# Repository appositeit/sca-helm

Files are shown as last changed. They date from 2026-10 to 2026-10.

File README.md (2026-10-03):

# sca-helm: standardised pressed SCA helms

This is a research and optimisation toolchain for a small family of pressed-steel helms for SCA armoured combat, initially targeting Lochac. It implements work steps 1–5 of [`docs/design_spec_v0.1.md`](docs/design_spec_v0.1.md).

> **Status: exploratory.** Every result is *geometric feasibility* on a surrogate population under labelled assumptions. Nothing here is a validated design or a claim about protection. The protective-stack, stability, retention and motion-range criteria are reported as **unevaluated** until physical tests exist ([`docs/validation_plan.md`](docs/validation_plan.md)).

## What is here

| Deliverable (spec §11) | Where |
| --- | --- |
| Rules register and current rules matrix | [`config/rules_register.yaml`](config/rules_register.yaml), [`docs/rules_matrix.md`](docs/rules_matrix.md) |
| Source, access and licensing register | [`config/data_sources.yaml`](config/data_sources.yaml), [`docs/data_sources.md`](docs/data_sources.md) |
| Population definition and data-quality report | [`docs/population.md`](docs/population.md), `outputs/*/data_quality.csv` |
| Foam test protocol, property schema, import path | [`docs/foam_test_protocol.md`](docs/foam_test_protocol.md) |
| Fit evaluator and coverage optimiser | `src/scahelm/fit.py`, `src/scahelm/optimise.py` |
| Coverage-vs-tooling plots; per-head assignment and exclusion CSVs | `outputs/<run>/` |
| Candidate dimensions, pad recipes, CAD (STEP/STL/DXF), all labelled EXPLORATORY | `outputs/<run>/candidate_*.csv`, `assignments.csv`, `cad/` |
| Manufacturing comparison, lower compatibility matrix, cost assumptions | [`docs/manufacturing.md`](docs/manufacturing.md), `outputs/<run>/lower_compatibility.csv` |
| Recommendation | [`docs/findings.md`](docs/findings.md) |

## Quick start

```bash
pip install -e .[test,step]          # step = OpenCASCADE bindings for STEP export (optional)
python -m pytest                     # numerical and geometric checks (~5 min)

python -m scahelm run --source synthetic --n 400            # SYNTHETIC fixture, no data needed
python -m scahelm ingest                                     # verify ANSUR II checksums, canonicalise
python -m scahelm run --source ansur2 --n 2000               # surrogate population run
python -m scahelm sweep --source ansur2 --n 900              # sensitivity scenarios (config/scenarios.yaml)
```

Each run writes `outputs/<source>_<scenario>/` containing:

- `SUMMARY.md`
- `manifest.json`: config hash, seed, dataset checksums, package versions, solver
- `config_used.yaml`
- coverage and min-cost tables
- bootstrap intervals
- `assignments.csv`: per head, the assembly, pose and pad recipe, or the exclusion reasons
- plots
- CAD files

## How it works (one paragraph per stage)

1. **Heads** (`heads.py`). Each participant is modelled as a smooth piecewise superquadric. It is built from measured head length, breadth, tragion-to-top height and circumference (which sets the squareness), plus face landmarks. Shape parameters that the scalar tables lack are drawn from *labelled* priors; see `docs/population.md`. Units are mm. Axes: x lateral, y anterior, z superior, with the origin at mid-tragion.
2. **Candidate crowns** (`shells.py`). There are two families:
   - a scaled single-shape *size-only* family;
   - a *shape-variable* grid over inner length, breadth and height.

   Both are smooth convex surfaces, so they have no undercuts. The minimum radius of curvature is enforced. The head-to-shell offset is calibrated so a typical head's pad gaps sit mid-window. *Lower components* (eye line, face-plate depth, chin drop) are offsets from each crown's interface, so every lower can actually be built on its crown.
3. **Liner** (`liner.py`). Discrete pad stacks come from a purchasable catalogue: a protective soft base plus firm or soft fitting layers. A linear series-spring screening model checks installed strain, contact pressure, the 12.7 mm minimum padding, maximum depth and compression reserve. **All foam properties are placeholders**, so stability stays unevaluated.
4. **Fit predicate** (`fit.py`, spec §7). Each criterion returns pass, fail or unevaluated. The geometric checks are:
   - hard contact (intrusion);
   - pad fill in five support zones;
   - unpadded clearance;
   - ear clearance;
   - seam bead;
   - eye line and vertical field of view;
   - nose and chin clearance;
   - the rules-derived 25.4 mm coverage below the chin.

   Head pose is searched over a bounded translation grid. Clearances are true surface distances (minimum over tangent planes for the convex shell), not radial differences. Discretisation bounds are added to the allowances. The fast path (a distance field) re-checks every near-threshold case exactly, and the tests confirm it reproduces the exhaustive evaluation.
5. **Selection** (`optimise.py`). Greedy set cover is the baseline, with an exact MILP (HiGHS via `scipy.optimize.milp`) over the finite catalogue. Dies are counted per architecture:
   - modular: one crown die set per family, with laser-cut lower variants at their own design cost;
   - integrated: each assembly is its own pressing;
   - left and right halves are distinct dies unless configured otherwise.

   The MILP is checked against exhaustive enumeration in the tests. Validation is held out by participant. The bootstrap re-runs the selection, so intervals include selection variability. Results are optimal **over the catalogue only**.

## Labelling conventions

Reports separate **retrieved facts** (rules, dataset properties), **design decisions**, **provisional scenarios** (`config/scenarios.yaml`) and **experimental results**. There are no experimental results yet. Config values carry `[RULE]`, `[DATA]`, `[ASSUMPTION]` or `[DECISION]` tags.

## Data

ANSUR II public files are stored unmodified in `data/raw/ansur2/` (US Army, cleared for unlimited public release), and their sha256 is checked on load. Restricted datasets must never be committed; `data/raw/restricted/` is git-ignored.

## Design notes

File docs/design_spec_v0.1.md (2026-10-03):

# Standardised pressed SCA helms: design and research specification

Version: 0.1 — 4 October 2026  
Status: engineering investigation and local-agent implementation brief; not a validated production design.

## 1. Objective

Design a manufacturable family of steel helms for adult SCA armoured combat, initially targeting Lochac. Minimise the number of expensive press forms while achieving acceptable fit for at least 90% of a defined target population. Fit must include liner stability, protective clearance, retention, vision and lower-head coverage, rather than merely containing the head.

The intended manufacturing approach is two pressed shell halves welded together, with a laser-cut grille and adaptable lower components. Investigate left/right halves joined along a sagittal seam as the working interpretation. Keep the split plane configurable: the original proposal did not establish it definitively. Compare this with a pressed crown plus fabricated lower assembly; do not silently substitute the latter architecture.

The initial deliverable is a reproducible research and optimisation toolchain, candidate dimensions and CAD geometry, and a physical validation plan. Do not assume that three or four forms will achieve 90% coverage; calculate it.

## 2. Design principles and scope

- Use adult external head geometry, including soft tissue, not bare bony skull geometry.
- Model size and shape jointly: length, breadth, height, occipital contour and forehead shape matter. Circumference and cephalic index are descriptive measurements, not sufficient fit criteria.
- Permit a small catalogue of foam materials and interchangeable pad thicknesses. Determine allowable shell oversize from measured displacement and liner behaviour.
- Separate crown geometry from lower face, jaw, eye-line and neck geometry where the manufacturing interface permits it.
- Optimise die cost, liner complexity and production effort together. Laser-cut variants still have assembly, stock and validation costs.
- Keep geometric fit, stability, impact performance and rules compliance as separate reported results.
- Preserve historically plausible appearance, with an open grille and good ventilation as initial preferences. Do not require one crown to support every historical helm type.

Out of scope for the first implementation: certifying protective performance, final press tooling manufacture, and claims about concussion prevention.

## 3. Evidence and rules register

Before fixing design limits, identify the current authoritative Lochac and Society requirements and record version, effective date, URL and relevant sections. Resolve superseded or conflicting documents. Maintain a machine-readable register linking each requirement to its source and verification method.

The official Lochac armour-requirements page retrieved for this brief states minimum completed steel thickness of 1.6 mm, resilient padding of at least 12.7 mm where the helm can contact the head unless an adequate suspension prevents injurious contact, and a separate retention requirement. These are research starting points pending verification against the applicable current handbook. Do not turn a padding-thickness rule directly into a geometric clearance rule without accounting for liner installation and compression.

Extract all applicable seam, face protection, opening, retention, screening, coverage and interior-projection rules. In particular, a laser-cut plate grille must be assessed as its actual geometry and material: a narrow rectangular ligament is not automatically equivalent to a permitted round bar. Distinguish ordinary armoured combat from missile-combat screening requirements.

The earlier discussion's 12.7–25 mm liner envelope, 5/10/15 mm fitting pads and estimated shell counts are hypotheses, not validated requirements. The suggestion that soft foam should be the impact layer and firm foam merely a fitting layer is also unproven: evaluate the whole stack.

## 4. Population and data acquisition

Define the denominator explicitly: ideally adults likely to participate in Lochac armoured combat. Public occupational or military samples are proxies. Report their limitations rather than claiming Australian population coverage from them.

Investigate these sources in order:

1. NIOSH anthropometric measurements and ISO digital headforms: establish exactly which individual records, cranial surfaces, weights and licences are downloadable.
2. Accessible military/civilian 3-D anthropometric collections, such as CAESAR or ANSUR-related resources: distinguish measurement tables from scans and check access/licensing.
3. EN 960 helmet-testing headforms as reproducible geometric references, subject to lawful access to the standard or licensed CAD. Standard headforms are test geometries, not a representative population sample.
4. A supplementary consenting local participant sample for checking population transfer and real fitting conditions.

Do not assume the complete NIOSH individual scan collection is public, or that respirator headforms fully describe cranial variation. Five representative forms cannot by themselves establish 90% coverage. If only scalar measurements are available, build an explicitly labelled surrogate model and identify which conclusions require scans.

For every source, record population, sample size, collection date, sampling method, exclusions, measurement definitions, scan coverage, units, licence, download URL and checksum. Preserve original files unmodified. Record missing or imputed measurements and avoid inventing independent combinations of marginal percentiles: correlation matters.

Use sample weights when justified; report unweighted results alongside weighted results. Include subgroup coverage and uncertainty where sample size supports it. Split training and validation by participant, never by scan. Repeated scans of one person must not inflate coverage.

## 5. Geometry and alignment

Use millimetres throughout. Define x as lateral, y as anterior, z as superior, with documented origin and anatomical landmarks. Preserve actual dimensions; no isotropic scale normalisation of heads. Establish a consistent anatomical orientation, then allow bounded rigid pose adjustment within the shell to model realistic fitting.

Clean and register meshes while retaining relevant asymmetry. Identify crown support zones, face exclusion regions, eyes, ears, jaw and neck landmarks. Incomplete cranial meshes must be flagged; do not reconstruct unseen crowns without reporting the assumption. Include hair/head covering and measurement uncertainty as configurable allowances.

Represent shell inner and outer surfaces separately. Fit uses the finished inner surface including seams, attachments and tolerances. Manufacturing starts from this finished shape, with sheet thickness, forming compensation and springback treated explicitly; an offset headform is not automatically a usable forming die.

A radial expression S(theta, phi) minus H(theta, phi) may be used for early visualisation only. It is not generally a true normal clearance and may fail for non-star-shaped regions. Use collision tests and surface distances with anatomically corresponding zones; report the direction and method. Sparse sampling must not miss local intrusions.

## 6. Liner material model and bench measurements

Start with two candidate foam grades, configurable by material ID; density alone is insufficient. Collect or measure compression stress–strain behaviour, rate dependence, hysteresis, compression set, creep, shear stiffness, temperature sensitivity, moisture response and attachment behaviour. Include the cover fabric and adhesive/fastener interfaces in assembly tests.

For a simple screening model, layers in series have approximate normal compliance sum(t_i / (E_i A)) and shear compliance sum(t_i / (G_i A)). This assumes small strain and ideal bonding. It is not a validated impact model. Real pads require nonlinear curves, contact changes and friction/slip behaviour.

Measure candidate stacks under defined preload and repeatable lateral forces/torques on a headform. Record translation in mm and rotation in degrees, creep duration and recovery. Define allowable movement through a documented engineering decision informed by eye-line, face clearance and practical use. Keep normal-use stability thresholds distinct from impact tests and retention/roll-off behaviour.

Treat pad thickness as discrete purchasable values. Account for compressed operating thickness, residual compression capacity, material variation and ageing. A thicker firm pad may reduce normal compression yet still permit shear or slip; prove its suitability experimentally.

Configuration must expose:

| Parameter | Initial status |
| --- | --- |
| Target population coverage | 0.90, configurable |
| Foam grades | Two candidate materials, properties to obtain |
| Minimum resilient padding | Rules-derived; verify current application |
| Maximum total liner depth | Unknown; derive from stack tests |
| Translation/rotation limits | Unknown; define and justify |
| Allowed pad catalogue and layouts | Candidate discrete choices |
| Fit preload and contact-pressure limits | To define |
| Head pose bounds | To define from eye-line and anatomy |
| Manufacturing and measurement allowances | To measure/estimate with provenance |

Run illustrative thickness sensitivity cases, including a provisional 12.7–25 mm total envelope, only when labelled as geometric scenarios. If material curves or movement limits are missing, report stability as unevaluated, not passed.

## 7. Fit predicate

For head h, shell s, lower component l, pad arrangement p and allowed pose q, define an acceptable assembly only if all relevant criteria pass:

1. No hard contact or intrusion, with tolerance and anatomical allowances included.
2. Required protective liner or valid suspension exists in every relevant contact region.
3. The permitted pad catalogue can fill support zones at acceptable preload and contact pressure without exceeding validated thickness or movement limits.
4. Adequate compression reserve and the separately validated protective-stack configuration are retained.
5. Eyes remain correctly positioned relative to the opening and grille through permitted movement; check field of view.
6. Nose, face, jaw and ears clear hard components; coverage remains compliant through the specified head/neck motion range.
7. The retention system works independently of snugness, and donning/removal remains practical.
8. Attachments, seam projections and lower interface do not create local failures.

Unpadded ventilation space need not have the same maximum distance as a supporting pad. Do not apply one universal upper-gap bound to the entire shell. Likewise, variation in pad thickness is not inherently a failure: evaluate stability, pressure distribution and manufacturability. A separate pad-asymmetry constraint may be explored as a heuristic, with its rationale stated.

The predicate must return pass/fail/unevaluated for each criterion, limiting zones, selected pose and exact pad recipe. Overall validated fit cannot pass when a required criterion is unevaluated. Maintain a cheaper geometric-feasibility result for exploratory optimisation.

## 8. Candidate shell family and optimisation

Build smooth, press-compatible candidate surfaces parameterised by cranial length, breadth, height, front/rear fullness and seam/interface geometry. Include scaled single-shape baselines and independently variable shape families. Impose minimum radii, die release, permitted draw direction and surface smoothness; do not export a jagged union of heads as a production surface.

An aligned union of padded head envelopes can initialise a candidate. Recheck it against every head after regularisation: enlarging the shell to fit one head may violate maximum usable padding for another.

For each candidate assembly j and participant i, precompute a feasibility matrix A_ij. With participant weights w_i, shell-selection variables x_j and coverage variables y_i, minimise selected tooling cost subject to:

    y_i <= sum_j A_ij * x_j
    sum_i w_i * y_i >= coverage_target * sum_i w_i

Use binary variables. Count shared dies separately from assembled variants: a left/right pair may require distinct tooling unless actual symmetry and press process permit reuse. Lower variants sharing a crown must not each count as another crown die, but must carry their own production costs.

Use greedy set cover as a baseline, then an integer solver for the finite candidate catalogue. Report whether optimality was proved, the solver gap and catalogue limitations. Do not call a catalogue optimum a global optimum over all possible surfaces. Consider iterative shape refinement, followed by independent validation.

Produce coverage curves for 1–6 shell families, extending if required. Compare size-only, shape-variable and modular-lower architectures. Report die count, complete assembly count, liner recipes, mass, estimated cost and excluded-head characteristics. Use sensitivity sweeps for foam limits, tolerances and coverage targets such as 85/90/95%. Report held-out coverage with confidence intervals; bootstrapping should account for the selection process.

## 9. Adaptive lower components

Define a repeatable crown-to-lower interface with datum surfaces, seam/joint details and a compatibility matrix. Explore lower variants for face length, jaw clearance, neck opening and eye-line. The attachment perimeter constrains which combinations are possible; do not assume an unrestricted cross-product.

Generate parametric laser-cut blanks for lower plates and grille with bend lines, radii, thickness, weld allowances and finish requirements. Check structural ligaments, attachments, face intrusion under deformation and applicable opening/screening requirements. Include gorget interaction and clearance while turning, looking up and looking down.

If using left/right pressed halves, compare integrating lower features into the pressing with trimming to a shared crown interface and adding separate lowers. Preserve the user's two-half welded construction as a candidate throughout the comparison.

## 10. Forming and fabrication investigation

Use nominal 2 mm mild steel as an initial material/process candidate, not a guarantee of adequate final thickness. Establish actual grade, ductility, thickness tolerance and forming limits. Investigate cold versus hot forming, staged draws, blank-holder requirements, lubrication, trimming, springback and weld distortion.

Estimate press force from a documented forming model and process assumptions. Do not select a press from projected area alone. Seek forming simulation or prototype evidence where useful. Record the number of operations and tooling pieces per shell family.

Measure finished thickness at the most strained regions, trim edges and ground seams. Validate seam quality, distortion and surface geometry. Define inspection methods and acceptance limits before production. Compare likely unit costs at explicitly stated batch volumes, including tooling amortisation, rejected parts, welding, finishing, liner assembly and inspection.

## 11. Local implementation and outputs

Prefer Python for data preparation, geometry evaluation and optimisation. Use an interchangeable geometry backend and an open solver where practical. Provide a documented command-line workflow; a web app is unnecessary. CAD output should be importable into Onshape: STEP for solid/surface geometry, STL for inspection/prototypes, DXF for laser-cut parts.

Suggested repository layout:

    README.md
    config/                 # units, rules, material models, scenarios
    data/raw/               # licensed source files or retrieval instructions
    data/processed/         # canonical measurements and meshes
    src/                    # ingest, align, fit, candidates, optimise, export
    tests/                  # meaningful numerical and geometric checks
    outputs/                # reports, tables, plots, candidate CAD
    docs/                   # sources, manufacturing and validation plans

Keep restricted datasets out of distributed repositories. Record dependency versions, seeds, solver configuration, dataset checksums and output provenance. Provide a small synthetic fixture that runs without restricted data, clearly labelled and excluded from population conclusions.

Required deliverables:

- Source/access/licensing register and current rules matrix.
- Explicit population definition and data-quality report.
- Foam test protocol, property schema and measured-data import path.
- Reproducible fit evaluator and coverage optimiser.
- Coverage-versus-tooling plots and per-head assignment/exclusion CSVs.
- Candidate dimension tables, pad recipes and CAD exports, each labelled exploratory or validated.
- Manufacturing comparison, lower compatibility matrix and cost assumptions.
- A recommendation explaining what is established, what is sensitive to assumptions and which measurements would most reduce uncertainty.

## 12. Verification and decision gates

Software checks must catch unit mistakes, incorrect mesh orientation, ignored collisions, pose-bound violations, discrete-pad errors and double-counted participants/tooling. Use known synthetic geometry and independently check a small optimiser instance by exhaustive enumeration. Confirm CAD export dimensions and that surface smoothing does not invalidate assignments.

Gate A — data: establish sufficient cranial information and defensible population coverage. If unavailable, deliver a surrogate feasibility study and a concrete acquisition plan.

Gate B — liner: measure the proposed stacks and establish justified normal-use movement limits. Recompute coverage with measured limits.

Gate C — geometry: build non-combat fit prototypes, checking boundary cases and deliberately excluded shapes. Compare predicted pad recipes and eye-line with observed fit.

Gate D — manufacture: form and weld steel prototypes, measure geometry and thickness, and inspect seams and grille construction.

Gate E — protection and use: develop appropriate instrumented impact, deformation, retention and repeat-impact tests with qualified input. Rules compliance and marshal inspection do not establish impact attenuation. Never use wearers as impact-test subjects. Validate complete assemblies, including liners and attachments, before recommending combat use.

## 13. Initial agent work sequence

1. Verify rules and source access; publish an evidence table without making shell-count claims.
2. Implement configuration, data schema and a synthetic end-to-end geometric example.
3. Ingest real measurements/scans where accessible; quantify missing cranial information.
4. Implement fit evaluation and candidate generation with provisional, explicitly labelled liner scenarios.
5. Produce initial coverage/tooling tradeoffs and identify boundary cases for foam and fit tests.
6. Integrate measured liner constraints, refine geometry and produce prototype-ready CAD when evidence permits.

Proceed through independent software/research tasks without requiring every unknown to be answered upfront. Keep unknown physical limits explicit and report blocked validation separately from completed exploratory work.

## 14. Reference starting points

- [Lochac armour requirements](https://sca.org.nz/wiki/index.php?title=Armoured_Combat:Armour_Requirements) — retrieved for this brief; verify current authority and effective rules.
- [Lochac Fighters' Handbook v3.4, July 2024](https://sca.org.nz/wiki/images/b/bc/Fighters_Handbook_v3.4_-_July_2024.pdf) — historical/versioned starting point; do not assume current.
- [NIOSH anthropometric data and ISO digital headforms](https://archive.cdc.gov/www_cdc_gov/niosh/npptl/topics/respirators/headforms/default.html) — archived official resource; investigate available files and their scope.
- [Helmet sizing research, PubMed record 1996936](https://pubmed.ncbi.nlm.nih.gov/1996936/) — research lead from the prior discussion; retrieve and verify methods and population before using numerical conclusions.
- EN 960, *Headforms for use in the testing of protective helmets* — locate the applicable edition and authorised geometry source; do not equate test-headform sizes with population coverage.

All implementation reports must distinguish retrieved facts, design decisions, provisional scenarios and experimental results.

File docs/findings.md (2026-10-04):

# Findings and recommendation (exploratory, 4 October 2026)

This page separates **retrieved facts**, **model results** (geometric feasibility on a surrogate population under labelled assumptions), **design decisions**, and **my opinions**. There are no experimental results yet. Nothing here says a helm protects anyone.

Main run: `outputs/ansur2_default/` (2,000 ANSUR II participants, 1,400 training and 600 held out, 255 crowns, 6,885 crown+lower assemblies). Sensitivity: `outputs/sweep/` (600 participants per scenario, coarser 12 mm catalogue).

## 1. Retrieved facts that constrain the design

The rules come from `rules_matrix.md`. The current documents are Lochac Fighters' Handbook v3.4 (in force since July 2024) and the Society Armored Combat Rattan Handbook V2026.0 (effective 22 September 2026). The Society text is newer and stricter in places, and kingdoms may not set lower standards without a variance. I found no Lochac variance for helms.

| Requirement | Governing value | Model use |
| --- | --- | --- |
| Finished steel thickness, face guard included | ≥ 1.6 mm at the thinnest point | Forming limit (see the manufacturing section) |
| Stock for a pressed or domed skull | ≥ 2.0 mm (Society "must") | Leaves at most 20% thinning |
| Resilient padding where the helm can contact the head | ≥ 12.7 mm | `liner.min_padding`. The basis (compressed or installed) is not stated, so both are swept. |
| Face guard extends below the chin and jaw | ≥ 25.4 mm | `lower.chin_coverage_margin` |
| 1 inch dowel must not enter any opening (Society) | Opening < 25.4 mm | DXF grille openings are ≤ 24 mm |
| Plate (laser-cut) grille in place of round bars | **No explicit rule. A marshal decision.** | Flagged; ask the Lochac Kingdom Armoured Combat Marshal (armoured@lochac.sca.org) |

**Data:**

- ANSUR II (US Army 2012) is the only public individual-level source with tragion-to-top height. It is stored and checksummed.
- NIOSH 2003 (civilian, n = 3,997) is public but lacks head height. It is a planned cross-check.
- No public full-cranium scan set covers this population. Headspace and LYHM need an academic signatory; CAESAR costs about AUD 1,770.
- **Gate A (data) is not passed.**

## 2. Model results: coverage vs tooling

Coverage is the weighted share of **held-out** heads that are geometrically feasible, with 15% female (an assumption). The numbers in brackets are bootstrap 5–95% intervals that re-run the selection.

| Press-die families | Size-only, one fixed lower | Size-only crowns + laser-cut lowers* | Shape-variable, lower pressed in | Shape-variable crowns + laser-cut lowers |
| --- | --- | --- | --- | --- |
| 1 | 0.45 [0.44–0.45] | 0.79 | 0.69 [0.68–0.69] | 0.79 [0.77–0.80] |
| 2 | 0.63 [0.56–0.63] | 0.95 | 0.85 [0.83–0.85] | 0.94 [0.87–0.90] |
| 3 | 0.67 [0.65–0.67] | 0.96 | 0.90 [0.89–0.92] | 0.97 [0.94–0.96] |
| 4 | 0.72 | 0.97 | 0.94 | 0.97 |
| 6 | 0.78 | 0.99 | 0.95 | 0.99 |

\*Computed from the saved feasibility matrix after the run, without a bootstrap.

On the bootstrap interval: when it lies below the point estimate (modular, k = 2), the full-sample selection did better on held-out heads than a typical re-selection. Use the interval, not the point estimate, as the expected out-of-sample figure.

**Cheapest tooling reaching each target** (training heads; tooling term only; AUD costs are placeholders, not quotes):

| Target | Modular: crown families / lowers / tooling | Integrated: families / tooling | Size-only, fixed lower |
| --- | --- | --- | --- |
| 85% | 2 / 2 / ~AUD 75k | 2 / AUD 96k | Unreachable (plateaus ~78%) |
| 90% | 2 / 4 / ~AUD 78k | 3 / AUD 144k | Unreachable |
| 95% | 3 / 6 / ~AUD 117k | 5 / AUD 240k | Unreachable |

Each family is a **pair** of dies (left and right halves). The modular min-cost solves stopped at the 60 s time limit, so they are the best solutions found, not proven minima. The integrated ones are proven optimal over the catalogue.

**Recommended exploratory set** (cheapest modular set reaching 90% on training heads; 91.8% held out):

| Crown | Inner length × breadth × height above tragion (mm) | Est. crown mass at 2 mm | Lower variants |
| --- | --- | --- | --- |
| S13 | 263 × 217 × 164 | 2.9 kg | 1 |
| G226 | 280 × 226 × 170 | 3.1 kg | 3 (eye line at 11 / 17 / 23 mm) |

- **Pads.** The typical installed gap is 21 mm. The common recipes are `soft12.7+soft12.7`, `soft19+firm10` and `soft19` (`assignments.csv` lists each head's recipe).
- **Coverage by sex.** Men 93% and women 83% (weighted). **Excluded women have smaller heads** (mean head length 184 mm, against 191 mm for included women). A third, smaller crown is the obvious remedy; the min-cost 95% solution adds one.
- **Why heads were excluded.** Field of view (71 heads), pad too loose (68), pad too tight (32), nose clearance (28), between pad steps (14).

## 3. What the results say, and how firmly

| Finding | Status | Reasoning |
| --- | --- | --- |
| A size-only family with one fixed lower cannot reach 85% at default assumptions | **Fairly robust.** It reaches 90% only with a wider pressure band or tighter tolerances, and then needs 10–12 sizes (section 4). | Face geometry (eye line, nose, chin) varies independently of skull size. A scaled lower cannot track it. |
| Laser-cut lower variants matter more than crown shape freedom | **Model result, sensitive to assumed face priors** | Size-only crowns with lowers match shape-variable crowns with lowers. Eye height, nose protrusion and chin set-back are *priors*, not measurements, so their spread decides how many lowers are needed. |
| Two or three crown families can cover about 90% of the proxy population geometrically | **Sensitive.** The answer runs from 1 to 6 families for liner depths of 35 to 25 mm, and reaches 4 with wider shape priors (section 4). | The fillable pad window (about 12–27.5 mm) lets one crown span roughly 15 mm of head size. The window comes from placeholder foam properties and pressure limits. |
| A modular architecture beats integrated on tooling cost at equal coverage | **Follows from the cost structure**, if laser-cut lowers really cost much less than pressed variants | The cost ratio is a placeholder |
| The ANSUR II proxy represents Lochac fighters | **Not established** | It is a military, US, aged 17–58, screened population. The sex mix is assumed. |

## 4. Sensitivity

Each scenario changes one assumption (`config/scenarios.yaml`). Every scenario uses 600 participants and a coarser 12 mm catalogue, so read the numbers relative to the sweep's own baseline, not the main run. Coverage is on held-out heads (180 per scenario, so about ±3 percentage points of noise). "Families for 90%" is the cheapest modular set reaching 90% on training heads.

| Scenario | Allowance (mm) | Size-only, fixed lower: k = 3 / 6 | Size-only: families for 90% | Modular: k = 1 / 2 / 3 | Modular: families for 90% |
| --- | --- | --- | --- | --- | --- |
| Baseline (sweep grid) | 7.3 | 0.75 / 0.77 | unreachable | 0.84 / 0.95 / 0.99 | 2 |
| Max liner depth 25 mm | 7.3 | 0.56 / 0.70 | unreachable | 0.60 / 0.74 / 0.80 | **6** |
| Max liner depth 35 mm | 7.3 | 0.73 / 0.78 | unreachable | 0.95 / 0.98 / 0.99 | **1** |
| 12.7 mm minimum on compressed thickness | 7.3 | 0.73 / 0.79 | unreachable | 0.82 / 0.96 / 0.98 | 2 |
| Wider contact-pressure band (0.5–20 kPa) | 7.3 | 0.86 / 0.89 | 10 | 0.92 / 0.99 / 1.00 | 2 |
| Tolerance 3 mm, hair/cap 5 mm | 10.8 | 0.49 / 0.59 | unreachable | 0.80 / 0.94 / 0.95 | 2 |
| Tolerance 0.75 mm, hair/cap 1.5 mm | 5.1 | 0.81 / 0.87 | 12 | 0.87 / 0.95 / 0.98 | 2 |
| 30% female | 7.3 | 0.74 / 0.77 | unreachable | 0.89 / 0.94 / 0.98 | 2 |
| Doubled spread on unmeasured shape priors | 8.2 | 0.51 / 0.58 | unreachable | 0.75 / 0.81 / 0.86 | **4** |

What the sweep shows (model results):

- **Maximum liner depth dominates.** Moving it from 25 mm to 35 mm changes the modular answer from 6 crown families to 1. That one number decides the size of the shell family, and it is a pure assumption until Gate B. (A 35 mm liner also makes a bigger, heavier helm; this sweep scores geometry only.)
- **Unmeasured shape variation is second.** Doubling the spread of the assumed cranial and face priors takes the modular answer from 2 families to 4. Real scans could move it either way.
- **The modular conclusion is stable.** Across tolerances, padding basis, pressure band and sex mix, the modular architecture still needs 2 families for 90%.
- **Size-only with a fixed lower reaches 90% only with favourable assumptions** (a wide pressure band or tight tolerances), and then needs 10–12 sizes. That is a manufacturing problem in its own right.
- **Tolerance and allowances matter more for size-only than for modular.** Lower variants absorb part of the face-geometry spread that a fixed lower cannot.

## 5. Recommendation

All of this is my opinion, based on the analysis above.

1. **Architecture.** Pursue left/right pressed crown halves trimmed to a shared interface, plus **laser-cut lower and grille variants** (the "modular" column). Keep the integrated pressing as a comparison only. In this model it costs about twice as much in tooling for the same coverage, and every eye-line or face-depth variant becomes a new die.
2. **Crown count.** Plan for **3 crown families** rather than 2. Two reach 90% on the proxy, but the third mainly serves smaller heads, which matters for women. The model figures also sit on unvalidated foam limits. Give each family 2–3 lower variants.
3. **Treat scaled crowns as a serious option.** If scaled versions of one master shape work as well as shape-variable ones, every die can share one design, one forming development and one inspection plan. Confirm with real cranial scans before committing.
4. **Do not cut tooling yet.** The two cheapest experiments with the biggest effect on the answer are:
   - **Foam bench tests** (`foam_test_protocol.md`). They set the fillable gap window, which drives crowns per family more than anything else in the sweep.
   - **A Lochac scan and measure day.** Roughly 50–100 fighters, full head with arming cap, plus eye height, nose and chin. This replaces the face priors that drive the lower-variant count, and fixes the sex mix.
5. **Ask the marshalate now.** Is a laser-cut plate grille acceptable, and with what ligament width and thickness? What is the occipital coverage expectation? Has Lochac adopted Society V2026.0? The answers change the lower design more than any geometry result.
6. **Next modelling steps:**
   - ingest the NIOSH table as a civilian cross-check (impute head height from the bitragion coronal arc);
   - replace independent shape priors with scan-derived correlations;
   - add pitch to the pose search once oriented landmarks exist.

## 6. Measurements that would most reduce uncertainty

This ranking is my judgement, informed by the sweep:

1. Foam compression and stability band, and maximum usable liner depth (Gate B).
2. Face landmarks relative to the cranium: pupil height above tragion, nose protrusion, chin set-back (Gate A scan day).
3. Formed-shell tolerance and springback (Gate D).
4. Lochac fighter sex mix and arming-cap thickness (one event, a clipboard).

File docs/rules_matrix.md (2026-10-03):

# SCA armoured (rattan) helm rules matrix: Lochac and Society

Retrieved: 2026-10-03. Machine-readable version: `config/rules_register.yaml`.
Quotes are verbatim unless marked *(paraphrase)*. **[OPINION]** marks engineering judgement that is not a rule.

## 1. Sources and authority

| ID | Document | Issuer | Version / date | Status |
|---|---|---|---|---|
| LOCHAC-FH-WIKI | [Lochac Fighters' Handbook ch.7 Armour requirements](https://rules.marshal.lochac.sca.org/index.php/Armoured_Combat:Armour_requirements) | Lochac Marshallate (approved by SCA Australia Ltd and SCA NZ Inc) | v3.4, effective 27 Jul 2024 (page edited 15 Jul 2025, link fixes only) | **Current** |
| LOCHAC-FH-PDF-2026 | [Live PDF render](https://rules.marshal.lochac.sca.org/index.php/Special:MakePdfBook/render/Armoured_Combat_-_Fighters_Handbook) | same | "Version 3.4 July 2024", generated 31 Jan 2026 | **Current** (helm text identical to the 2024 PDF) |
| LOCHAC-FH-PDF-2024 | [Fighters_Handbook_v3.4_-_July_2024.pdf](https://rules.marshal.lochac.sca.org/images/b/bc/Fighters_Handbook_v3.4_-_July_2024.pdf) | same | generated 25 Jul 2024 | Current content, static copy. The given sca.org.nz URL now redirects to the wiki Main Page. |
| LOCHAC-NZ-LEGACY | sca.org.nz `Armour_Requirements` page | SCANZ legacy wiki | — | **Superseded** (page has no text; the wiki moved in Oct 2025) |
| LOCHAC-GLOSSARY | [Glossary](https://rules.marshal.lochac.sca.org/index.php/Armoured_Combat:Glossary) | Lochac | v3.4 | Current |
| LOCHAC-CHANGELOG | [Change log](https://rules.marshal.lochac.sca.org/index.php/Armoured_Combat:Change_log) | Lochac | to 12 Jul 2025 | Current |
| LOCHAC-CA-EXEMPTION | [Combat Archery Exemption](https://rules.marshal.lochac.sca.org/index.php/Armoured_Combat:Combat_Archery_Exemption) | Society Earl Marshal, SCA Inc. | 2 Dec 2011 | Current (still hosted; no revocation found, though that is not independently confirmed) |
| LOCHAC-MH-INSPECT | [Marshals' Handbook: Inspecting equipment](https://rules.marshal.lochac.sca.org/index.php/Armoured_Combat:Inspecting_equipment) | Lochac | current | Current (no helm checklist) |
| LOCHAC-MARSHAL-SITE | marshal.lochac.sca.org/?p=6 | Lochac EM website | newest item Jul 2021 | **Superseded/stale** |
| SCA-AC-RATTAN-2026 | [Armored Combat - Rattan Handbook](https://www.sca.org/wp-content/uploads/2026/09/Armored_Combat_-_Rattan_-_Handbook_2026Sept.pdf) | SCA Inc. Society Marshal / Board | V2026.0, approved 23 Jun 2026, **effective 22 Sep 2026** | **Current** (the PDF is the authoritative version) |
| SCA-WIKI-ARMOR | [Society wiki: Armor](https://society-rules.fullmesh.co.nz/index.php/Armored_Combat:Equipment_standards_-_Armor) | SCA Inc. | online | Reference only |
| SCA-CL-2025-06 | [Society change log, 23 Jun 2025](https://society-rules.fullmesh.co.nz/index.php/Armored_Combat:Change_log_-_23_June_2025) | SCA Inc. | full rebuild | Historical (it replaced the Oct 2023 handbook) |
| SCA-HB-UPDATES | [Handbook updates policy](https://society-rules.fullmesh.co.nz/index.php/Armored_Combat:Handbook_updates) | SCA Inc. | — | Current |

**Newest Lochac version:** I found nothing newer than v3.4 for armoured combat. The Lochac wiki's news items after July 2024 cover fencing (Oct 2025), the wiki migration (Oct 2025) and youth combat (Jan 2026), not adult armoured rules.

**Hierarchy:** Society 1.2.1(b) says kingdoms "cannot reduce or disregard the requirements and standards delineated in the Society handbooks without a variance". Lochac sits under the affiliates SCA Australia Ltd and SCA NZ Inc, and affiliates may request a deferral (SCA-HB-UPDATES). I found no deferral or variance for the helm rules. The only known variance is the 2011 combat-archery exemption.

## 2. Requirements matrix

Type: A = all armoured combat, M = missile scenarios only (arrows/bolts), B = both.

| ID | Topic | Type | Lochac v3.4 (current) | Society V2026.0 (current) | Governing value to design to |
|---|---|---|---|---|---|
| HELM-GEN-01 | Helm required | B | 7.4.1.1 "your head must be protected by a helmet constructed in compliance with these rules." | 12.4.1.1: helm plus neck protection; "a bevor could form part of the face protection." | — |
| HELM-GEN-02 | Edges and fastening | B | 7.1 "All armour must be free of sharp edges." | 12.1.8 "All metal must be free of sharp edges." | Deburr and radius every edge |
| HELM-COV-01 | Coverage | B | 7.4.1.2 "sufficient coverage to protect the bones of the skull and face … necessary to protect the bones of your jaw … not considered essential to completely armour the soft tissue in the underside of the jaw." | 12.4.2.1 identical | Skull including occiput, face and jaw bones. **No numeric occipital figure exists.** |
| HELM-COV-02 | Areas | B | 7.3.1 head, neck, face, throat, cervical vertebrae and T1 | 12.2.1(a) same | Helm and gorget together cover down to T1 |
| HELM-THK-01 | Thickness | B | 7.4.1.3 "steel no less than 1.6mm thickness (16 gauge), or of equivalent material, **when completed**. Steel of less than 1.6mm is too thin, even if it is sold as 16 gauge." Applies to the helm **including the face guard**. | 12.4.2.2 "**cold-rolled** steel no less than 1/16 inch (1.6 mm) thickness, or of equivalent material, when completed. A1008 is the most common type" | **≥ 1.6 mm finished, at the thinnest point, including the face guard** |
| HELM-THK-02 | 18 ga | A | 7.4.1.3 "1.3mm/18ga helms may not be used by any combatants" | — | Prohibited for combatants |
| HELM-THK-03 | Thinning processes | B | 7.4.1.4 doming, sinking, spinning or excessive grinding: the top "**should** be made from a minimum of 2.0mm (14 gauge)" | 12.4.2.3 the top "**must** be made from a minimum of 5/64 inch (2.0 mm)" | **≥ 2.0 mm stock for a pressed/domed skull, and ≥ 1.6 mm finished** |
| HELM-MAT-01 | Alternative materials | B | 7.4.1.5 stainless, brass, bronze OK if "equivalent to 1.6mm thick steel" | 12.4.2.4 "structurally equivalent to 1/16 inch (1.6 mm) thick cold-rolled steel"; (a) proof to the Kingdom EM for approval | Thinner high-strength or hardened steel needs EM approval. **Neither source gives a hardness figure.** |
| HELM-MAT-02 | Mass | B | 7.4.1.6 titanium, fibreglass etc. may not make it lighter than a 1.6 mm steel helm | 12.4.2.5 adds aluminum and "ultra-light materials" | Mass ≥ the same helm in 1.6 mm steel |
| HELM-MAT-03 | Steel type | B | Glossary: "Cold- or hot-rolled mild steel" | Cold-rolled | Cold-rolled |
| HELM-JNT-01 | Seams | B | 7.4.1.7(a)–(c): welded inside and outside, a single full-penetration bead, or lap joints welded/brazed at both edges | 12.4.2.6(a)–(c) same | Same |
| HELM-JNT-02/03 | Rivets | B | 7.4.1.7(d) iron/steel, pitch ≤ 63.5 mm (2½ in); no screw or pop rivets | 12.4.2.6(d) solid steel/SS 3.18–4.76 mm at pitch ≤ 38.1 mm (1½ in); or solid steel/SS/brass ≥ 4.76 mm at pitch ≤ 63.5 mm; **no blind**, screw or pop rivets | Society |
| HELM-INT-01 | Interior projections | B | 7.4.1.8 "no major projections on the inside … Minor projections … must be padded." | 12.4.2.7 same | No number is given for "major" |
| HELM-PAD-01 | Head padding | B | 7.4.1.9 "minimum of 12.7mm (1/2 inch) of resilient material, or suspended" | 12.4.2.8 same | **≥ 12.7 mm resilient foam, or a suspension system** |
| HELM-PAD-02 | Neck/body contact padding | B | "**should** be padded" | 12.4.2.9 "**must** be padded with a minimum of 1/2 inch (12.7 mm)" | Society: 12.7 mm |
| HELM-RET-01 | Chinstrap | B | 7.4.1.10 strap or equivalent (helm-to-breastplate strap, chin cup); "A 'snug fit' is not an equivalent"; strap "**minimum 13mm** in width"; must not strangle | 12.4.2.10 also must "prevent metal from contacting your face"; bevor counts as an equivalent; strap ≥ 12.7 mm | **≥ 13 mm** (Lochac) |
| HELM-FG-01 | Face guard extent | B | 7.5.1 "completely cover the face opening … extend at least 25.4mm (1 inch) below the bottom of the chin and jaw line when the head is held erect" | 12.4.3.2 same 1 in | ≥ 25.4 mm below chin/jaw line |
| HELM-FG-02/03 | Openings | B | 7.5.2 "prevent a 25.4mm (1 inch) dowel from **contacting the wearer's face**" | 12.4.3.1 "prevent a 1 inch (25.4 mm) diameter dowel from **entering into any** of the face guard openings"; inspection 27.3.6.2(b): "face guard and eye slots do not have openings greater than 1 inch" | **Every aperture, including eye slots, must have an inscribed circle < 25.4 mm** |
| HELM-FG-04/05 | Bars | B | 7.5.4 "steel of not less than 4.76mm (3/16 in) in diameter, or equivalent. If the gap between supporting cross-bars is less than 50.8mm (2 in), 3.18mm (1/8 in) diameter bars may be used." | 12.4.3.3 same (written as 4.8 / 3.2 mm) | ≥ 4.76 mm, or ≥ 3.18 mm where the unsupported span is < 50.8 mm |
| HELM-FG-06 | Closure | B | 7.5.5 attached and secured closed, minimal chance of detaching or opening | 12.4.3.4 (movable visor) same | Positive latch |
| HELM-FG-07 | Interior mounting | B | 7.5.6 "should not attach to the interior of the helm unless of structurally superior design and workmanship" | **Removed** in June 2025 | Prefer exterior mounting |
| HELM-FG-08 | Screening underlay | B | 7.5.3 screening not equivalent to 1.6 mm steel "must be underlain by a legal **plate or bar grille** face guard" | — | The grille must be legal with the screen removed |
| HELM-FG-09 | Face standoff | B | — | 27.3.6.2(c) marshal push test: "A gentle touch of the tip of the nose … undesirable, but not grounds to disqualify" | Design clearance allowing for liner compression |
| HELM-NECK-01 | Neck/gorget | B | 7.7.1 the helm; a rigid gorget **plus 6 mm resilient** padding; a mail/leather camail (6 mm padding where it touches); or a heavy leather collar plus 6 mm | 12.4.5.1 the helm; a rigid gorget (no padding figure); a 4.4 mm/11 oz leather collar plus 6 mm closed-cell foam; camail padded 6 mm where contact is likely | Lochac for the gorget (6 mm padding). "Rigid" = steel ≥ 18 ga (Lochac) / ≥ 1.27 mm (Society). |
| HELM-PLM-01 | Plume | A | 7.4.2 plumed participants need a plume ≥ 30 cm above the helm top, attached at rear/top; no plumes in war | — | Only if offering a socket |
| HELM-EYE-01 | Eyewear | B | 7.6 shatterproof lenses only | 12.4.4 same | — |
| HELM-MSL-01 | Archery screening | **M** | 7.5.7 "In scenarios involving missile combat using arrows or bolts, all openings in the face guard larger than **5mm** across must be covered by well-secured screening." | **No screening rule.** Arrows rely on blunts/APDs that must not penetrate "a legal face guard" (16.1.2.3–4) | Lochac: openings ≤ 5 mm in missile configuration |
| HELM-MSL-02 | Perforated plate | M | 7.5.7(a) "Perforated steel no less than 1.6mm thick. Perforations will be no more than 5 mm, with less than 50% open surface area." | — | t ≥ 1.6, holes ≤ 5 mm, open area < 50 % |
| HELM-MSL-03 | Mesh types | M | 7.5.7(b) woven steel mesh, wire ≥ 1.6 mm, openings ≤ 5 mm; (c) Crimsafe; (d) no window screen or galvanised hardware cloth; (e) 12 kg fencing-mask mesh; (f) other mesh that does not deform under a 12 kg mask tester; (g) maille openings ≤ 5 mm | — | — |
| HELM-MSL-04 | Screen retention | M | 7.5.8 secured "against sideways movement, and vertical" | — | — |
| HELM-MSL-05 | Exemption condition | M | 2011 exemption: "Archery mesh" required for all combatants and marshals when Lochac arrows are in use | (the variance itself) | — |
| HELM-MSL-06 | Penetration allowance | M/A | — | Fletches, thrown weapons and thrusting tips may not penetrate a legal face guard by more than **12.7 mm (½ in)** (16.1.1.4(a), 15.4.1, 27.4.2) | **[OPINION]** keep > 12.7 mm, plus padding compression, between the grille's inner surface and the face |
| HELM-NC-01 | Marshal helm | M | 7.15.2 non-combatants may use 1.3 mm (18 ga) steel and "fewer bars underlying permanently attached screening"; large yellow cross on the rear; marshalling only | 12.9 eye protection only (ANSI Z87.1, fencing mask, or a legal helm) | Separate variant only |

**Conversions used by the sources:**

| Imperial | Metric | Note |
|---|---|---|
| 1/16 in | 1.5875 mm | Quoted as 1.6 mm, "16 gauge" |
| 5/64 in | 1.98 mm | Quoted as 2.0 mm, "14 gauge" |
| 1/20 in | 1.27 mm | 18 ga; Lochac rounds to 1.3 mm |
| 3/16 in | 4.7625 mm | Lochac 4.76; Lochac glossary 4.5 (wrong); Society 4.8 |
| 1/8 in | 3.175 mm | Quoted as 3.18 / 3.2 |
| 1 in | 25.4 mm | |
| 2 in | 50.8 mm | |
| 1/2 in | 12.7 mm | Lochac chinstrap uses 13 mm |
| 2½ in | 63.5 mm | |
| 1½ in | 38.1 mm | |
| 1/4 in | 6.35 mm | Quoted as 6 mm |

The Gauge glossary note says commercial 16 ga is often "0.058 or even 0.055 inch" (1.47 / 1.40 mm), which is "much too thin for helms."

> **External fact, not from the rules:** US Manufacturers' Standard Gauge gives 16 ga = 0.0598 in (1.52 mm) and 14 ga = 0.0747 in (1.90 mm). Buying "16 gauge" therefore fails the 1.6 mm rule, and buying "14 gauge" falls short of a literal 2.0 mm.

## 3. Open questions / conflicts

1. **Lochac v3.4 is older than the 2025/2026 Society helm text.** On these points the Society rule is stricter than Lochac and so, under Society 1.2.1(b), it should apply:
   - "must" 2.0 mm stock for thinning processes;
   - cold-rolled steel;
   - 38.1 mm rivet pitch for small rivets, and blind rivets banned;
   - 12.7 mm padding where the helm touches the neck or body;
   - the dowel may not enter any opening (Lochac only says it may not contact the face).

   SCA-HB-UPDATES lets affiliates defer changes. **I found no Lochac adoption announcement or deferral. Confirm with the Lochac Kingdom Armoured Combat Marshal (armoured@lochac.sca.org).** In the meantime, design to the stricter value.
2. **Interior-mounted face guards.** Lochac 7.5.6 discourages them; Society removed that rule. This is unresolved, so mount the grille on the exterior.
3. **Bar diameter inconsistency.** Lochac 7.5.4 says 4.76 mm but the Lochac glossary says "3/16 inch (4.5mm)". The span condition is "< 2 in" in the rule body but "2 inches or less" in both glossaries. Use 4.76 mm and a span strictly under 50.8 mm.
4. **Perforated plate open area.** The Figure 7.3 captions say "50% Open area" while the rule says "less than 50%". Design to < 50 %.
5. **Is perforated 1.6 mm plate "equivalent to 1.6mm steel"** under 7.5.3? If not, it needs a legal grille underneath. The rules do not say. Ask the Kingdom Armoured Combat Marshal (KACM).
6. **Rear-of-skull / occipital coverage** has no numeric definition anywhere. It is covered only by "bones of the skull". The fit evaluator needs a project-defined headform landmark, for example below the inion. That choice is a project decision, not a rule.
7. **Hardness and high-strength steels.** Neither source mentions hardness. Equivalence is decided by the EM (Society 12.4.2.4(a)). Lochac experimental programmes need EM approval plus approval from the SCA Ltd and SCANZ boards.
8. **Status of the 2011 combat-archery exemption.** It is still hosted on the current Lochac wiki, but I could not independently confirm it is still in force.
9. **Unverified items.** The given sca.org.nz URLs no longer serve the documents; I verified the same content at rules.marshal.lochac.sca.org. lochac.sca.org Earl Marshal pages other than marshal.lochac.sca.org (which is stale) were not checked.

## 4. Implications for a laser-cut plate grille

**Rules (factual):**
- Plate grilles are a recognised face-guard type: Lochac 7.5.3 refers to "a legal **plate or bar grille** face guard".
- **No rule in either source addresses laser-cut plate grilles specifically.** No minimum web width, kerf, heat-affected-zone or edge-finish rule exists.
- The bar rule (7.5.4 / 12.4.3.3) is written for round "bars … in diameter, or equivalent". How it applies to rectangular plate webs is a matter of marshal or EM judgement under "or equivalent". **Needs confirmation with the KACM.**
- The plate is part of "your helm, including the face guard", so it must be **≥ 1.6 mm when completed**. Measure after deburring or grinding.
- Every aperture, including eye slots, must stop a 25.4 mm dowel from entering. That means the largest inscribed circle must be < 25.4 mm (Society 12.4.3.1, 27.3.6.2(b)). Under Lochac 7.5.2 the dowel must also not reach the face.
- The face guard must extend ≥ 25.4 mm below the chin/jaw line (7.5.1).
- All cut edges must be free of sharp edges (7.1 / 12.1.8).
- For Lochac arrow and bolt scenarios, any opening over 5 mm must be screened (7.5.7). A grille cut as perforated plate (t ≥ 1.6 mm, holes ≤ 5 mm, open area < 50 %) is itself a listed screening type (7.5.7(a)). Whether it also removes the need for an underlying grille is open question 5.
- For Lochac only: an exterior attachment is preferred (7.5.6).

**[OPINION] Engineering equivalence estimate.** This is not a rule; it is a first-pass sizing aid only. The assumption is a flat web bent through its thickness by a face-on blow.

To match the elastic bending strength (section modulus Z) of a round bar, the web width must be at least w = 6·Z_bar / t².
- Z for a 4.76 mm round bar is about 10.6 mm³.
- Z for a 3.18 mm round bar is about 3.1 mm³.

Using plastic modulus instead (round bar d³/6, rectangle w·t²/4) gives somewhat larger widths.

| Plate t | Web width w for a 4.76 mm bar | Web width w for a 3.18 mm bar (span < 50.8 mm) |
|---|---|---|
| 1.6 mm | ≈ 25 mm (plastic ≈ 28) | ≈ 7.4 mm (plastic ≈ 8.3) |
| 2.0 mm | ≈ 16 mm (plastic ≈ 18) | ≈ 4.7 mm (plastic ≈ 5.3) |
| 3.0 mm | ≈ 7.1 mm (plastic ≈ 8.0) | ≈ 2.1 mm (plastic ≈ 2.4) |

- **Bending stiffness** (second moment of area) is far harder to match with thin plate. A 1.6 mm web would need to be about 74 mm wide to equal a 4.76 mm bar's I of about 25 mm⁴.
- Curvature or flanging of a pressed grille, and a 2-D web network, add a lot of stiffness. That should be checked by FEA or a physical test, for example comparing against a reference bar grille under a rattan impact.
- The numbers suggest a **thicker grille plate (≥ 3 mm) or a formed or flanged plate** is the practical way to argue "equivalent" while keeping useful sight lines.
- Take a documented equivalency case (calculation plus test) to the Lochac KACM/EM before production.

**[OPINION] Inner-face clearance.** Society rules allow weapons to intrude up to 12.7 mm into a legal face guard. The grille's inner surface should therefore clear the face by more than 12.7 mm plus liner compression.

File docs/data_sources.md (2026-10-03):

# Head-geometry data sources: access, licensing and fitness for purpose

Compiled 2026-10-03. The machine-readable version is `config/data_sources.yaml`. Anything marked *unverified* was not confirmed against a primary source. AUD figures are indicative and use the ECB rates for 2026-10-02 (1 EUR = 1.6176 AUD, 1 USD = 1.4411 AUD, 1 NZD = 0.80872 AUD).

Target population: adult SCA heavy-combat fighters in Lochac (Australia and New Zealand). Most are male but not all. They cover a broad adult age range and wear padding or arming caps under the helmet.

## 1. Summary register

| id | Source | Population / n | Data type | Scan coverage | Access | Licence | Cost (AUD) |
|---|---|---|---|---|---|---|---|
| ansur2_2012 | ANSUR II public working DB | US Army 2010–12; 4082 M / 1986 F; age 17–58 | Individual manual measurements, 93 dims | none public | public download | US Gov, "unlimited public release" | 0 |
| ansur1_1988 | ANSUR (I) public files | US Army 1988; 1774 M / 2208 F | Individual measurements (has bitragion coronal arc) | none | public download | US Gov (wording unverified) | 0 |
| niosh_2003_headface | NIOSH 2003 head-and-face survey | US respirator users; 2543 M / 1454 F; 3 age bands from 17/18 to 66 | Individual manual measurements, 19 head/face dims | none (scans not released) | public download (data.cdc.gov) | no explicit licence; US Gov work, presumed PD (unverified) | 0 |
| niosh_iso_digital_headforms | NIOSH/ISO 16900-5 digital headforms | 5 averaged headforms (5 subjects each) | STL + IGES meshes | full head, with constructed scalp | public download | as above | 0 |
| headspace_york | Headspace (Univ. of York) | UK; 1519 scans | 3dMD full-head scans in latex caps, OBJ, landmarks, metadata | full head | academic agreement, university staff signatory | non-commercial university research only | 0 |
| lyhm | Liverpool-York Head Model | 1212 Headspace subjects | 3DMM shape space | full head model | academic agreement | non-commercial | 0 |
| flame | FLAME / FLAME 2023 Open | >33k scans (orig.), incl. CAESAR | 3DMM | full head model (cranium quality unverified) | registration | 2023 Open: CC-BY-4.0; older: academic NC | 0 |
| caesar_wear | CAESAR via WEAR | NA/IT/NL civilians c. 2000, several thousand | Whole-body scans + landmarks + tables; unregistered | full body (head coarse, hair uncapped; unverified) | paid, posted drive | "do anything you like" | 1771 (962 WEAR member) |
| size_korea | Size Korea | Korean; >8500 head scans (secondary) | scans + tables | full head (reported) | unverified | unverified | unknown |
| sizeusa | SizeUSA ([TC]2) | US ~10,800 | body scans | full body | paid, on request | commercial | unknown |
| facebase_3dfn | FaceBase 3D Facial Norms | US, 3–40 y, 2454 | 3dMD face surfaces + calipers | face only | IRB-approved craniofacial research only | DUC | 0 |
| adf_awas_2012 | AUS Warfighter Anthropometry Survey (DSTO-TR-3006) | ADF Army 2012, n unverified | summary stats for 84 dims; body scans exist | none public | report public (DTIC 403 to this agent) | public release report | 0 |
| rmit_cyclists_2015 | RMIT Australian cyclists head scans | Melbourne; 176 M / 46 F; 34.6±12.5 y | handheld 3D head scans + hair-thickness offset | full head | papers only; data by request (unverified) | unverified | unknown |
| size_australia | Size Oz / Target–Alvanon 2012 | AU retail survey | body scans | proprietary | unavailable | – | – |
| en960_2006 | EN 960:2006 / BS EN 960:2006 | – | Headform geometry standard (sizes 445–645) | idealised | purchase | © CEN/BSI | ~136 (iTeh, USD 94.47) |
| iso_6220 | ISO/DIS 6220:1983 | – | Draft, withdrawn; basis of EN 960 | – | unavailable | – | – |
| asnzs_2512_1_2009 | AS/NZS 2512.1:2009 | – | Headforms A–Q, AA | idealised | purchase | © Standards Australia | 154.97 (web reader) / 172.02 (hardcopy) |
| pubmed_1996936 | Sippo & Belyavin 1991 | RAF aircrew 1970/71 survey (~2000) | Method paper | – | abstract public | – | – |

## 2. Detail on the key sources

### 2.1 ANSUR II (downloaded and stored)

- Landing page: https://www.openlab.psu.edu/ansur2/. The OpenLab site uses the `tools.openlab.psu.edu` host for downloads. The space-named `wp-content` URLs returned 404 or a connection reset.
- Licence: the NSRDEC memo of 14 Apr 2017 says the files were "reviewed and cleared for UNLIMITED PUBLIC RELEASE". **Decision:** keep the raw files unmodified in `data/raw/ansur2/`.

| File | URL | HTTP | Bytes | Rows × cols | sha256 |
|---|---|---|---|---|---|
| ANSUR_II_MALE_Public.csv | https://tools.openlab.psu.edu/publicData/ANSUR_II_MALE_Public.csv | 200 | 2,000,794 | 4082 × 108 | `0547aea0170e5293de519389981135e75803f02e6d40c77ace740decc0caac64` |
| ANSUR_II_FEMALE_Public.csv | https://tools.openlab.psu.edu/publicData/ANSUR_II_FEMALE_Public.csv | 200 | 976,573 | 1986 × 108 | `ed7e800aa97a4d42f8286b988be2fe1883a2e789588169db959864b707d1757a` |

**Head-related columns.** These are the exact names and are the same in both files:
`headcircumference`, `headlength`, `headbreadth`, `tragiontopofhead`, `bitragionchinarc`, `bitragionsubmandibulararc`, `bizygomaticbreadth`, `mentonsellionlength`, `earbreadth`, `earlength`, `earprotrusion`, `interpupillarybreadth`, `neckcircumference`, `neckcircumferencebase`.

**Not present:** sagittal arc, bitragion coronal arc, bitragion frontal arc, minimum frontal breadth, head height. ANSUR I has `BITR-CORONAL_ARC` and `BITR-CRINION_ARC`. NIOSH has `BITCOR` and `BITFRONT`.

Quirks:
- The ID column is `subjectid` in the male file and `SubjectId` in the female file.
- The male file has one Latin-1 byte, so read it with `encoding="latin-1"`.
- `weightkg` is measured body mass in units of 0.1 kg.
- **`Weightlbs` is self-reported body weight, not a sampling weight.** Its minimum is 0, which marks a missing value. `Heightin` is also self-reported.
- `interpupillarybreadth` values run from 510 to 770, which suggests units of 0.1 mm. The memo says all dimensions are in mm (*unverified*).

Sampling: the public files are the "working databases". Each is a stratified random subsample, drawn separately for each sex from the 7435 M / 3922 F measured. The strata are age, race/ethnicity and component, matched to the DMDC Army census of 30 Sep 2011. The files are therefore self-weighting for the 2011 Army, and **there is no weight column**. Female soldiers with braids or cornrows were measured *with* hair for head breadth, circumference, length and tragion–top of head.

Observed values, mean (SD) in mm:

| | headcircumference | headlength | headbreadth | tragiontopofhead |
|---|---|---|---|---|
| Male | 574.4 (16.0) | 199.5 (7.0) | 154.3 (5.5) | 131.1 (6.2) |
| Female | 561.1 (19.4) | 189.8 (7.4) | 147.8 (5.2) | 126.5 (6.5) |

ANSUR II also collected 3-D head, foot and whole-body scans. They are **not public**, for participant privacy.

### 2.2 NIOSH anthropometric data and ISO digital headforms

The archived CDC page links to `cdc.gov/niosh/data/datasets/rd-10130-2020-0`, which redirects to data.cdc.gov dataset `c2hx-eeis`. The dataset has a single zip file:
`https://data.cdc.gov/api/views/c2hx-eeis/files/4b4cb188-f59c-490a-8ab1-67528503554a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`. The download returned HTTP 200: 68,582,780 bytes, sha256 `f8633144d49cfd64aea2305edf8244d25d32bf12af596456e00f91ae1d5c5e8b`. It was downloaded for inspection and **not stored**, because only ANSUR files were authorised.

- **The individual-level 2003 table is public.** `datasets/RespiratorUsersData-all-subjects.csv` holds 3997 subjects (2543 M, 1454 F) with these columns: SUBNO, SEX, AGEGRP (3 bands), RACEGRP, WEIGHTKG, STATURE, HEADCIRC, BITCOR, BITFRONT, BITSUBN, BITCHIN, NECKCIRC, HEADBR, HEADLTH, MINFRBR, MAXFRBR, BIZYGOBR, BIGONLBR, NROOTBR, NOSEBR, LIPLTH, SUBNASAL, MENSELL, NOSEPRO, INTPUPBR. Missing values are coded -9,999, and some fields use thousands separators.
- `RespiratorUsers-scanned-subjects.csv` holds the same measurements for the 946 scanned subjects. **The individual scans themselves are not released.** The methods PDF says 1013 subjects were scanned and the CDC text says 947.
- The archived page says the 2D/3D data are available "for those who complete the data use agreements". The current zip contains the 2D table with no agreement step.
- Headforms: there are five symmetric STL and IGES meshes (small, medium, large, long/narrow, short/wide), each covering the full head and neck. The archived page mentions PLY files, but none are in the zip.
  - The face is an average of 5 subjects.
  - The **scalp is constructed**, scaled to the category's mean head length and breadth, because the subjects had hair or wore wig caps.
  - The ears are generic surfaces from a third party.
- Licence: none is stated (data.cdc.gov `license: null`). As a US federal work it is presumed public domain (*unverified*). The third-party ear surfaces are a residual uncertainty.
- Head circumference, mean (SD): male 576.1 (17.5) mm, female 558.7 (20.7) mm.

### 2.3 Full-head 3-D scan resources

| Source | What you get | Blocking issue for this project |
|---|---|---|
| Headspace (York) | 1519 capped full-head 3dMD scans (38 GB) with metadata | Needs a university academic signatory; non-commercial research only |
| LYHM | Morphable model built from Headspace | Same licence |
| FLAME 2023 Open | Morphable head model, CC-BY-4.0 (per site), requires registration | Cranial accuracy and training data *unverified*; built for faces |
| CAESAR (WEAR) | Unregistered whole-body scans, >33 GB, permissive use | Low head resolution and uncapped hair (*unverified*); €1095 (≈ AUD 1771) |
| RMIT cyclists | 222 Melbourne head scans with hair-offset correction | Data access unknown; contact the authors |
| Size Korea / SizeUSA | Scans | Population mismatch or price unknown; *unverified* |
| FaceBase 3DFN | Face scans | Face only, IRB-restricted |

### 2.4 Australian sources

- **AWAS 2012** (DSTO-TR-3006, Edwards et al., Aug 2014, approved for public release) gives summary values for 84 dimensions. Body scans were collected. Individual data are not public. The DTIC PDF returned 403 to this agent, so it needs to be fetched manually to confirm the head dimensions and sample size.
- **No national civilian head dataset exists.** Size Oz was never funded, and the Target/Alvanon 2012 survey is proprietary.

### 2.5 Helmet test headform standards

- **EN 960:2006** supersedes EN 960:1994/A1:1998. It derives from ISO/DIS 6220:1983, which was withdrawn as a draft, and ISO/R 1511.
  - It defines full, three-quarter and half headforms.
  - Size designation is the nominal circumference: **445–645 mm in 10 mm steps**.
  - Table 1 gives h, x, y and z. For example, h runs from 108.5 mm at size 445 to 150.5 mm at size 645 (from the public preview). Mass bands of 3100 ± 100 g up to 6100 ± 180 g also appear, but the size grouping is *unverified*.
  - Annex A gives the normative spherical coordinates for each size, in 15° steps. Annex B gives the radius equations for sizes 495–645.
  - No licensed CAD file was found. The geometry has to be rebuilt from Annex A.
  - Prices: iTeh USD 94.47 (≈ AUD 136). Standards NZ quotes NZD 605.25 (≈ AUD 489, *unverified*). The BSI GBP price is *unverified*.
- **AS/NZS 2512.1:2009** is Current in Australia. It defines headforms A–Q and AA. Prices: AUD 154.97 (web reader, 1 user) or AUD 172.02 (hardcopy), both including GST.

### 2.6 PubMed 1996936

Sippo AC, Belyavin AJ (RAF Institute of Aviation Medicine). *Determining aircrew helmet size design requirements using statistical analysis of anthropometric data.* Aviat Space Environ Med 1991;62(1):67–74.

- **Data:** the 1970/71 RAF survey of 2000 aircrew.
- **Method:** head length, breadth and pupil–vertex height were plotted for each subject, and the minimum number of sizes giving a reasonable fit was calculated.
- **Finding:** **nine sizes fit 93.5%** of subjects grouped around the mean. Fitting more people would need many more sizes or a looser fit.

## 3. Limitations for representing Lochac fighters

- None of the accessible individual-level datasets is Australian or New Zealander. ANSUR is a fit, young-skewed US military sample with a US racial mix. NIOSH covers US civilian workers aged 18–66; it is race-stratified rather than proportional, which affects reweighting.
- Manual caliper values compress hair and soft tissue a little. Scans with hair inflate breadths (NIOSH documents both effects).
- The cranial vault shape above the brow line is the key region for a helmet. It is described only by circumference, length, breadth, tragion–top (ANSUR II) and bitragion coronal arc (NIOSH, ANSUR I). No public dataset gives an individual cranial surface.
- SCA helmets are worn over padding and arming caps. An offset for this has to be modelled separately.

## Recommendation: what to use for a surrogate model now, and an acquisition plan for scans

**Use now, at no cost and with public licences:**

1. **The ANSUR II tables (stored) form the main statistical backbone.** Use `headcircumference`, `headlength`, `headbreadth` and `tragiontopofhead`, with `bizygomaticbreadth` and `mentonsellionlength` for face opening and visor clearance.
   - Model men and women separately.
   - Mix them in Lochac proportions as a user parameter. The real ratio is unknown, so treat it as an assumption.
   - To get closer to AU/NZ, reweight by `DODRace`/`SubjectNumericRace`, with a sensitivity analysis.
2. **The NIOSH 2003 individual table** (public; re-download from the URL above if it is approved for storage) is a civilian, older cross-check. It adds the bitragion coronal and frontal arcs (`BITCOR`, `BITFRONT`), which constrain crown height and shape. It has head circumference, length and breadth in common with ANSUR II, so the two can be compared and pooled.
3. **The NIOSH ISO digital headforms (STL)** serve as template meshes and face geometry. Morph them (e.g. RBF or landmark-driven) to the statistical L/B/height/circumference targets to make a family of synthetic heads, such as boundary manikins on a PCA of the head dimensions. Treat the vault shape as a low-confidence assumption, because the scalp was constructed.
4. **Use EN 960 size designations** (circumference in 10 mm steps) as the shell sizing and labelling scheme. Buy EN 960 (≈ AUD 136) only if the project needs compatibility with test headforms. Use Sippo & Belyavin's 9 sizes ≈ 93.5% as a benchmark when choosing the number of sizes.
5. **Check FLAME 2023 Open** (CC-BY-4.0, registration) as an openly licensed shape space. Verify its cranial coverage before relying on it.

**Acquisition plan for real full-head scans:**

1. **Short term, AUD 0.** Email the RMIT authors (Perret-Ellena, Subic, Pang) about access to the 222 Australian head scans and the derived headforms. Fetch DSTO-TR-3006 manually to get ADF Army head statistics for validating the surrogate.
2. **Academic route, AUD 0.** If a university collaborator in AU or NZ can sign, request Headspace and LYHM under the York agreement. Usage must stay non-commercial research, so check whether the project's output qualifies before relying on it.
3. **Paid route, ≈ AUD 1771 (WEAR member ≈ AUD 962).** CAESAR scans are permissively licensed, but the heads are low-resolution and uncapped. Use them only if 1 and 2 fail.
4. **Best long term: collect Lochac scans directly.**
   - Use a phone- or tablet-based structured-light or photogrammetry scanner. Scan each subject in a tight swim or latex cap, and again with their usual arming cap or padding, with consent and a de-identification protocol.
   - Add three tape measurements per subject for calibration: circumference, sagittal arc and coronal arc.
   - Even 50–100 fighters, sampled at events across kingdoms and baronies, would directly cover the target population and the padding offset.

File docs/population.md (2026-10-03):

# Population definition and surrogate model

Status: design decision plus assumptions. Revisit when a Lochac sample exists (Gate A).

## Denominator

**Target population:** adults who take part in Lochac armoured (rattan) combat, wearing their usual arming cap or padding.

No head data exists for this group. Every run therefore uses a **proxy** and says which one:

| Proxy | Used for | Why it is not the target population |
| --- | --- | --- |
| ANSUR II 2012 (US Army, 4082 M / 1986 F) | All population runs | Military, US, aged 17–58, with fitness and height screening. Body build and ethnic mix differ from AU/NZ. The public file is a stratified subsample, and it has no survey weights. |
| NIOSH 2003 (US respirator users, 3997) | Planned cross-check | Civilian and older, so arguably closer to SCA demographics. It is not ingested yet (see `data_sources.md`). |
| Synthetic fixture | Tests and the demo only | Generated numbers. **Never** report population coverage from it. |

**Weights.** ANSUR II has no sampling weights. The only re-weighting applied is post-stratification by sex, so the weighted female share equals `population.female_fraction`. The default of **0.15 is an assumption**; a marshal-roster count would replace it. Every run reports both weighted and unweighted held-out coverage.

**Splits.** Training and validation are split by participant, stratified by sex, with 30% held out. ANSUR has one row per person. The code rejects duplicate participant ids, so a future scan dataset with repeat scans cannot leak one person across the split.

## What the scalar tables give, and what is assumed

Each head is a smooth piecewise superquadric (`src/scahelm/geometry.py`), built in millimetres with the tragion mid-point as origin.

| Parameter | Source |
| --- | --- |
| Head length, head breadth (max-length plane) | Measured (`headlength`, `headbreadth`) |
| Tragion to vertex height | Measured (`tragiontopofhead`) |
| Horizontal squareness exponent | **Fitted** so the section perimeter equals measured `headcircumference` |
| Menton-sellion length, ear protrusion, interpupillary breadth | Measured. ANSUR stores IPD in 0.1 mm, which is converted. |
| Split of length in front of/behind tragion (`f_front`) | **Assumed** prior N(0.50, 0.02) |
| Height of max-length plane above tragion | **Assumed** N(32, 5) mm |
| Vertical squareness, occipital depth | **Assumed** priors |
| Pupil, sellion, pronasale and menton offsets | **Assumed** priors |

The assumed parameters are drawn **independently** of each other and of the measurements. In reality they are correlated, and this model leaves those correlations out. That is the main reason the results are labelled a *surrogate*. The sensitivity scenario `shape_prior_wide` doubles their spread to show how much the conclusions depend on them.

## Conclusions this model can and cannot support

| Can support (with stated assumptions) | Needs 3-D scans |
| --- | --- |
| How coverage scales with the number of size families, given the size distribution | Whether a given *shape* family fits real occipital or forehead contours |
| Rough ranking of the size-only, shape-variable and modular architectures | Local pressure points and hot spots |
| Which liner and tolerance assumptions coverage is most sensitive to | Eye-line position relative to the brow; nose and chin clearance (offsets are priors) |
| Boundary heads to recruit for physical fit tests | Any claim about Lochac population coverage |

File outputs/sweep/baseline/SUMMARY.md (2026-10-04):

# Run summary: baseline

**ansur2 surrogate (scalar measurements + assumed shape priors)**. All coverage figures are *geometric feasibility* under the configured
assumptions. `validated_fit` is **unevaluated** for every head because foam stability, retention,
protective-stack and motion-range criteria have no measured data yet (spec section 7).

- Heads: 600; catalogue: 97 crowns, 2619 crown+lower assemblies
- Calibrated radial offset 30.0 mm; allowances 7.32 mm
  (incl. sampling bound 1.82 mm); fillable pad gap 11.9-27.5 mm
- Config hash `086af5ad4a77`, seed 20261003, runtime 744 s
- Optimality is over this finite catalogue only; it is not a global optimum over surfaces.

## Coverage by number of press-die families

| architecture | families | train_cov | train_cov_greedy | val_cov | status | mip_gap |
|---|---|---|---|---|---|---|
| size_only | 1 | 0.489 | 0.489 | 0.535 | optimal | 0.000 |
| size_only | 2 | 0.621 | 0.604 | 0.653 | optimal | 0.000 |
| size_only | 3 | 0.697 | 0.668 | 0.750 | optimal | 0.000 |
| size_only | 4 | 0.730 | 0.725 | 0.763 | optimal | 0.000 |
| size_only | 5 | 0.762 | 0.754 | 0.792 | optimal | 0.000 |
| size_only | 6 | 0.789 | 0.776 | 0.770 | optimal | 0.000 |
| shape_integrated | 1 | 0.702 | 0.702 | 0.773 | optimal | 0.000 |
| shape_integrated | 2 | 0.844 | 0.811 | 0.855 | optimal | 0.000 |
| shape_integrated | 3 | 0.916 | 0.904 | 0.919 | optimal | 0.000 |
| shape_integrated | 4 | 0.951 | 0.928 | 0.964 | optimal | 0.000 |
| shape_integrated | 5 | 0.970 | 0.952 | 0.981 | optimal | 0.000 |
| shape_integrated | 6 | 0.979 | 0.967 | 0.981 | optimal | 0.000 |
| modular | 1 | 0.804 | 0.801 | 0.839 | optimal | 0.000 |
| modular | 2 | 0.957 | 0.905 | 0.951 | optimal | 0.000 |
| modular | 3 | 0.984 | 0.977 | 0.990 | optimal | 0.000 |
| modular | 4 | 0.991 | 0.987 | 0.974 | optimal | 0.000 |
| modular | 5 | 0.994 | 0.991 | 0.990 | optimal | 0.000 |
| modular | 6 | 0.994 | 0.994 | 0.974 | optimal | 0.000 |

`val_cov`: the training-selected set scored on held-out participants (participant-level split).
`val_p05/p95`: bootstrap interval that re-runs selection on resampled training heads.

## Cheapest tooling reaching each coverage target (training heads)

Tooling costs are placeholder AUD assumptions (config `costs`), for ranking only.

| architecture | target | status | mip_gap | tooling_cost_AUD | crown_families | press_die_sets | press_dies | complete_assemblies | train_cov | val_cov |
|---|---|---|---|---|---|---|---|---|---|---|
| size_only | 0.850 | infeasible_target | nan | nan | 0 | 0 | 0 | 0 | 0.000 | 0.000 |
| size_only | 0.900 | infeasible_target | nan | nan | 0 | 0 | 0 | 0 | 0.000 | 0.000 |
| size_only | 0.950 | infeasible_target | nan | nan | 0 | 0 | 0 | 0 | 0.000 | 0.000 |
| shape_integrated | 0.850 | optimal | 0.000 | 144000.000 | 3 | 3 | 6 | 3 | 0.904 | 0.924 |
| shape_integrated | 0.900 | optimal | 0.000 | 144000.000 | 3 | 3 | 6 | 3 | 0.911 | 0.919 |
| shape_integrated | 0.950 | optimal | 0.000 | 192000.000 | 4 | 4 | 8 | 4 | 0.951 | 0.934 |
| modular | 0.850 | optimal | 0.000 | 76500.000 | 2 | 2 | 4 | 3 | 0.852 | 0.863 |
| modular | 0.900 | optimal | 0.000 | 78000.000 | 2 | 2 | 4 | 4 | 0.903 | 0.884 |
| modular | 0.950 | optimal | 0.000 | 81000.000 | 2 | 2 | 4 | 6 | 0.957 | 0.951 |

## Recommended exploratory set

cheapest modular set reaching 0.9 on training heads: `S11-L20, G055-L11, G055-L20, G055-L23`

| crown_id | inner_length | inner_breadth | inner_height_above_tragion | crown_mass_kg_est | status |
|---|---|---|---|---|---|
| S11 | 257.314 | 213.260 | 160.195 | 2.750 | EXPLORATORY |
| G055 | 267.000 | 216.000 | 174.000 | 2.930 | EXPLORATORY |

Exclusion reasons (heads not fitted by the recommended set; a head may have several):

| status | n |
|---|---|
| reason:pad_too_tight | 15 |
| reason:pad_between_steps | 14 |
| reason:field_of_view | 13 |
| reason:nose | 10 |
| reason:pad_too_loose | 8 |
| reason:eye_line | 1 |

Per-head assignment, pose and pad recipe: `assignments.csv`. Excluded-head characteristics:
`excluded_characteristics.csv`. CAD (EXPLORATORY): `cad/`.

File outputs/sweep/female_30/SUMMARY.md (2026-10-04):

# Run summary: female_30

**ansur2 surrogate (scalar measurements + assumed shape priors)**. All coverage figures are *geometric feasibility* under the configured
assumptions. `validated_fit` is **unevaluated** for every head because foam stability, retention,
protective-stack and motion-range criteria have no measured data yet (spec section 7).

- Heads: 600; catalogue: 97 crowns, 2619 crown+lower assemblies
- Calibrated radial offset 30.0 mm; allowances 7.32 mm
  (incl. sampling bound 1.82 mm); fillable pad gap 11.9-27.5 mm
- Config hash `89d3c34589ca`, seed 20261003, runtime 803 s
- Optimality is over this finite catalogue only; it is not a global optimum over surfaces.

## Coverage by number of press-die families

| architecture | families | train_cov | train_cov_greedy | val_cov | status | mip_gap |
|---|---|---|---|---|---|---|
| size_only | 1 | 0.463 | 0.463 | 0.478 | optimal | 0.000 |
| size_only | 2 | 0.603 | 0.575 | 0.646 | optimal | 0.000 |
| size_only | 3 | 0.673 | 0.668 | 0.741 | optimal | 0.000 |
| size_only | 4 | 0.720 | 0.717 | 0.772 | optimal | 0.000 |
| size_only | 5 | 0.756 | 0.752 | 0.755 | optimal | 0.000 |
| size_only | 6 | 0.780 | 0.774 | 0.772 | optimal | 0.000 |
| shape_integrated | 1 | 0.676 | 0.676 | 0.754 | optimal | 0.000 |
| shape_integrated | 2 | 0.845 | 0.819 | 0.866 | optimal | 0.000 |
| shape_integrated | 3 | 0.910 | 0.902 | 0.933 | optimal | 0.000 |
| shape_integrated | 4 | 0.948 | 0.939 | 0.962 | optimal | 0.000 |
| shape_integrated | 5 | 0.965 | 0.960 | 0.978 | optimal | 0.000 |
| shape_integrated | 6 | 0.979 | 0.972 | 0.956 | optimal | 0.000 |
| modular | 1 | 0.779 | 0.778 | 0.885 | optimal | 0.000 |
| modular | 2 | 0.945 | 0.910 | 0.936 | optimal | 0.000 |
| modular | 3 | 0.981 | 0.974 | 0.978 | optimal | 0.000 |
| modular | 4 | 0.990 | 0.988 | 0.967 | optimal | 0.000 |
| modular | 5 | 0.995 | 0.993 | 0.972 | optimal | 0.000 |
| modular | 6 | 0.995 | 0.995 | 0.972 | optimal | 0.000 |

`val_cov`: the training-selected set scored on held-out participants (participant-level split).
`val_p05/p95`: bootstrap interval that re-runs selection on resampled training heads.

## Cheapest tooling reaching each coverage target (training heads)

Tooling costs are placeholder AUD assumptions (config `costs`), for ranking only.

| architecture | target | status | mip_gap | tooling_cost_AUD | crown_families | press_die_sets | press_dies | complete_assemblies | train_cov | val_cov |
|---|---|---|---|---|---|---|---|---|---|---|
| size_only | 0.850 | infeasible_target | nan | nan | 0 | 0 | 0 | 0 | 0.000 | 0.000 |
| size_only | 0.900 | infeasible_target | nan | nan | 0 | 0 | 0 | 0 | 0.000 | 0.000 |
| size_only | 0.950 | infeasible_target | nan | nan | 0 | 0 | 0 | 0 | 0.000 | 0.000 |
| shape_integrated | 0.850 | optimal | 0.000 | 144000.000 | 3 | 3 | 6 | 3 | 0.889 | 0.882 |
| shape_integrated | 0.900 | optimal | 0.000 | 144000.000 | 3 | 3 | 6 | 3 | 0.902 | 0.922 |
| shape_integrated | 0.950 | optimal | 0.000 | 240000.000 | 5 | 5 | 10 | 5 | 0.954 | 0.956 |
| modular | 0.850 | optimal | 0.000 | 76500.000 | 2 | 2 | 4 | 3 | 0.881 | 0.889 |
| modular | 0.900 | optimal | 0.000 | 78000.000 | 2 | 2 | 4 | 4 | 0.904 | 0.893 |
| modular | 0.950 | time_limit | 0.273 | 115500.000 | 3 | 3 | 6 | 5 | 0.953 | 0.939 |

## Recommended exploratory set

cheapest modular set reaching 0.9 on training heads: `S11-L20, G055-L11, G055-L20, G055-L23`

| crown_id | inner_length | inner_breadth | inner_height_above_tragion | crown_mass_kg_est | status |
|---|---|---|---|---|---|
| S11 | 257.314 | 213.260 | 160.195 | 2.750 | EXPLORATORY |
| G055 | 267.000 | 216.000 | 174.000 | 2.930 | EXPLORATORY |

Exclusion reasons (heads not fitted by the recommended set; a head may have several):

| status | n |
|---|---|
| reason:pad_too_tight | 15 |
| reason:pad_between_steps | 14 |
| reason:field_of_view | 13 |
| reason:nose | 10 |
| reason:pad_too_loose | 8 |
| reason:eye_line | 1 |

Per-head assignment, pose and pad recipe: `assignments.csv`. Excluded-head characteristics:
`excluded_characteristics.csv`. CAD (EXPLORATORY): `cad/`.

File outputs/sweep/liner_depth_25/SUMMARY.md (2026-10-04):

# Run summary: liner_depth_25

**ansur2 surrogate (scalar measurements + assumed shape priors)**. All coverage figures are *geometric feasibility* under the configured
assumptions. `validated_fit` is **unevaluated** for every head because foam stability, retention,
protective-stack and motion-range criteria have no measured data yet (spec section 7).

- Heads: 600; catalogue: 97 crowns, 2619 crown+lower assemblies
- Calibrated radial offset 27.0 mm; allowances 7.32 mm
  (incl. sampling bound 1.82 mm); fillable pad gap 11.9-22.8 mm
- Config hash `d917f9e7451b`, seed 20261003, runtime 1092 s
- Optimality is over this finite catalogue only; it is not a global optimum over surfaces.

## Coverage by number of press-die families

| architecture | families | train_cov | train_cov_greedy | val_cov | status | mip_gap |
|---|---|---|---|---|---|---|
| size_only | 1 | 0.243 | 0.243 | 0.303 | optimal | 0.000 |
| size_only | 2 | 0.378 | 0.369 | 0.412 | optimal | 0.000 |
| size_only | 3 | 0.466 | 0.466 | 0.556 | optimal | 0.000 |
| size_only | 4 | 0.543 | 0.543 | 0.615 | optimal | 0.000 |
| size_only | 5 | 0.588 | 0.588 | 0.636 | optimal | 0.000 |
| size_only | 6 | 0.620 | 0.620 | 0.698 | optimal | 0.000 |
| shape_integrated | 1 | 0.368 | 0.368 | 0.394 | optimal | 0.000 |
| shape_integrated | 2 | 0.571 | 0.546 | 0.582 | optimal | 0.000 |
| shape_integrated | 3 | 0.668 | 0.668 | 0.680 | optimal | 0.000 |
| shape_integrated | 4 | 0.725 | 0.725 | 0.751 | optimal | 0.000 |
| shape_integrated | 5 | 0.772 | 0.768 | 0.791 | optimal | 0.000 |
| shape_integrated | 6 | 0.806 | 0.800 | 0.803 | optimal | 0.000 |
| modular | 1 | 0.499 | 0.499 | 0.602 | optimal | 0.000 |
| modular | 2 | 0.691 | 0.690 | 0.738 | optimal | 0.000 |
| modular | 3 | 0.801 | 0.794 | 0.803 | optimal | 0.000 |
| modular | 4 | 0.851 | 0.841 | 0.846 | optimal | 0.000 |
| modular | 5 | 0.893 | 0.882 | 0.895 | optimal | 0.000 |
| modular | 6 | 0.919 | 0.908 | 0.905 | optimal | 0.000 |

`val_cov`: the training-selected set scored on held-out participants (participant-level split).
`val_p05/p95`: bootstrap interval that re-runs selection on resampled training heads.

## Cheapest tooling reaching each coverage target (training heads)

Tooling costs are placeholder AUD assumptions (config `costs`), for ranking only.

| architecture | target | status | mip_gap | tooling_cost_AUD | crown_families | press_die_sets | press_dies | complete_assemblies | train_cov | val_cov |
|---|---|---|---|---|---|---|---|---|---|---|
| size_only | 0.850 | infeasible_target | nan | nan | 0 | 0 | 0 | 0 | 0.000 | 0.000 |
| size_only | 0.900 | infeasible_target | nan | nan | 0 | 0 | 0 | 0 | 0.000 | 0.000 |
| size_only | 0.950 | infeasible_target | nan | nan | 0 | 0 | 0 | 0 | 0.000 | 0.000 |
| shape_integrated | 0.850 | optimal | 0.000 | 384000.000 | 8 | 8 | 16 | 8 | 0.852 | 0.871 |
| shape_integrated | 0.900 | optimal | 0.000 | 528000.000 | 11 | 11 | 22 | 11 | 0.900 | 0.854 |
| shape_integrated | 0.950 | optimal | 0.000 | 816000.000 | 13 | 17 | 34 | 17 | 0.950 | 0.904 |
| modular | 0.850 | time_limit | 0.292 | 195000.000 | 5 | 5 | 10 | 10 | 0.854 | 0.848 |
| modular | 0.900 | time_limit | 0.215 | 237000.000 | 6 | 6 | 12 | 14 | 0.901 | 0.895 |
| modular | 0.950 | time_limit | 0.139 | 355500.000 | 9 | 9 | 18 | 21 | 0.950 | 0.920 |

## Recommended exploratory set

cheapest modular set reaching 0.9 on training heads: `S11-L20, S14-L02, S14-L20, S14-L23, S19-L13, S19-L20, S19-L23, G053-L02, G053-L19, G070-L11, G070-L22, G071-L01, G071-L10, G071-L20`

| crown_id | inner_length | inner_breadth | inner_height_above_tragion | crown_mass_kg_est | status |
|---|---|---|---|---|---|
| S11 | 251.302 | 207.249 | 157.189 | 2.660 | EXPLORATORY |
| S14 | 258.208 | 212.944 | 161.509 | 2.780 | EXPLORATORY |
| S19 | 269.718 | 222.437 | 168.708 | 2.990 | EXPLORATORY |
| G053 | 261.000 | 210.000 | 147.000 | 2.720 | EXPLORATORY |
| G070 | 273.000 | 210.000 | 159.000 | 2.850 | EXPLORATORY |
| G071 | 273.000 | 210.000 | 171.000 | 2.910 | EXPLORATORY |

Exclusion reasons (heads not fitted by the recommended set; a head may have several):

| status | n |
|---|---|
| reason:pad_too_tight | 28 |
| reason:pad_between_steps | 14 |
| reason:pad_too_loose | 9 |
| reason:nose | 8 |
| reason:field_of_view | 4 |

Per-head assignment, pose and pad recipe: `assignments.csv`. Excluded-head characteristics:
`excluded_characteristics.csv`. CAD (EXPLORATORY): `cad/`.

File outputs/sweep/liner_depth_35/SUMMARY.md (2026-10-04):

# Run summary: liner_depth_35

**ansur2 surrogate (scalar measurements + assumed shape priors)**. All coverage figures are *geometric feasibility* under the configured
assumptions. `validated_fit` is **unevaluated** for every head because foam stability, retention,
protective-stack and motion-range criteria have no measured data yet (spec section 7).

- Heads: 600; catalogue: 97 crowns, 2619 crown+lower assemblies
- Calibrated radial offset 33.0 mm; allowances 7.32 mm
  (incl. sampling bound 1.82 mm); fillable pad gap 11.9-32.2 mm
- Config hash `825050d1c390`, seed 20261003, runtime 701 s
- Optimality is over this finite catalogue only; it is not a global optimum over surfaces.

## Coverage by number of press-die families

| architecture | families | train_cov | train_cov_greedy | val_cov | status | mip_gap |
|---|---|---|---|---|---|---|
| size_only | 1 | 0.531 | 0.531 | 0.602 | optimal | 0.000 |
| size_only | 2 | 0.670 | 0.631 | 0.685 | optimal | 0.000 |
| size_only | 3 | 0.730 | 0.715 | 0.734 | optimal | 0.000 |
| size_only | 4 | 0.755 | 0.746 | 0.743 | optimal | 0.000 |
| size_only | 5 | 0.773 | 0.765 | 0.777 | optimal | 0.000 |
| size_only | 6 | 0.784 | 0.783 | 0.782 | optimal | 0.000 |
| shape_integrated | 1 | 0.841 | 0.841 | 0.874 | optimal | 0.000 |
| shape_integrated | 2 | 0.934 | 0.913 | 0.962 | optimal | 0.000 |
| shape_integrated | 3 | 0.970 | 0.963 | 0.957 | optimal | 0.000 |
| shape_integrated | 4 | 0.989 | 0.981 | 0.976 | optimal | 0.000 |
| shape_integrated | 5 | 0.994 | 0.988 | 0.990 | optimal | 0.000 |
| shape_integrated | 6 | 0.997 | 0.994 | 0.976 | optimal | 0.000 |
| modular | 1 | 0.920 | 0.910 | 0.952 | optimal | 0.000 |
| modular | 2 | 0.988 | 0.960 | 0.981 | optimal | 0.000 |
| modular | 3 | 0.995 | 0.991 | 0.988 | optimal | 0.000 |
| modular | 4 | 0.997 | 0.995 | 0.997 | optimal | 0.000 |
| modular | 5 | 0.997 | 0.997 | 0.993 | optimal | 0.000 |
| modular | 6 | 0.997 | 0.997 | 0.993 | optimal | 0.000 |

`val_cov`: the training-selected set scored on held-out participants (participant-level split).
`val_p05/p95`: bootstrap interval that re-runs selection on resampled training heads.

## Cheapest tooling reaching each coverage target (training heads)

Tooling costs are placeholder AUD assumptions (config `costs`), for ranking only.

| architecture | target | status | mip_gap | tooling_cost_AUD | crown_families | press_die_sets | press_dies | complete_assemblies | train_cov | val_cov |
|---|---|---|---|---|---|---|---|---|---|---|
| size_only | 0.850 | infeasible_target | nan | nan | 0 | 0 | 0 | 0 | 0.000 | 0.000 |
| size_only | 0.900 | infeasible_target | nan | nan | 0 | 0 | 0 | 0 | 0.000 | 0.000 |
| size_only | 0.950 | infeasible_target | nan | nan | 0 | 0 | 0 | 0 | 0.000 | 0.000 |
| shape_integrated | 0.850 | optimal | 0.000 | 96000.000 | 2 | 2 | 4 | 2 | 0.907 | 0.935 |
| shape_integrated | 0.900 | optimal | 0.000 | 96000.000 | 2 | 2 | 4 | 2 | 0.934 | 0.962 |
| shape_integrated | 0.950 | optimal | 0.000 | 144000.000 | 3 | 3 | 6 | 3 | 0.951 | 0.971 |
| modular | 0.850 | optimal | 0.000 | 39000.000 | 1 | 1 | 2 | 2 | 0.879 | 0.916 |
| modular | 0.900 | optimal | 0.000 | 40500.000 | 1 | 1 | 2 | 3 | 0.910 | 0.943 |
| modular | 0.950 | optimal | 0.000 | 76500.000 | 2 | 2 | 4 | 3 | 0.951 | 0.981 |

## Recommended exploratory set

cheapest modular set reaching 0.9 on training heads: `S15-L11, S15-L13, S15-L20`

| crown_id | inner_length | inner_breadth | inner_height_above_tragion | crown_mass_kg_est | status |
|---|---|---|---|---|---|
| S15 | 272.630 | 227.019 | 168.968 | 3.020 | EXPLORATORY |

Exclusion reasons (heads not fitted by the recommended set; a head may have several):

| status | n |
|---|---|
| reason:pad_too_loose | 27 |
| reason:field_of_view | 22 |
| reason:pad_too_tight | 7 |
| reason:pad_between_steps | 2 |

Per-head assignment, pose and pad recipe: `assignments.csv`. Excluded-head characteristics:
`excluded_characteristics.csv`. CAD (EXPLORATORY): `cad/`.

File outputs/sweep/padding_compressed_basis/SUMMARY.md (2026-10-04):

# Run summary: padding_compressed_basis

**ansur2 surrogate (scalar measurements + assumed shape priors)**. All coverage figures are *geometric feasibility* under the configured
assumptions. `validated_fit` is **unevaluated** for every head because foam stability, retention,
protective-stack and motion-range criteria have no measured data yet (spec section 7).

- Heads: 600; catalogue: 97 crowns, 2619 crown+lower assemblies
- Calibrated radial offset 31.5 mm; allowances 7.32 mm
  (incl. sampling bound 1.82 mm); fillable pad gap 15.0-27.5 mm
- Config hash `9c28bc4c6b0a`, seed 20261003, runtime 813 s
- Optimality is over this finite catalogue only; it is not a global optimum over surfaces.

## Coverage by number of press-die families

| architecture | families | train_cov | train_cov_greedy | val_cov | status | mip_gap |
|---|---|---|---|---|---|---|
| size_only | 1 | 0.477 | 0.477 | 0.505 | optimal | 0.000 |
| size_only | 2 | 0.610 | 0.603 | 0.655 | optimal | 0.000 |
| size_only | 3 | 0.686 | 0.681 | 0.733 | optimal | 0.000 |
| size_only | 4 | 0.721 | 0.713 | 0.763 | optimal | 0.000 |
| size_only | 5 | 0.749 | 0.738 | 0.772 | optimal | 0.000 |
| size_only | 6 | 0.768 | 0.762 | 0.789 | optimal | 0.000 |
| shape_integrated | 1 | 0.691 | 0.691 | 0.710 | optimal | 0.000 |
| shape_integrated | 2 | 0.864 | 0.829 | 0.863 | optimal | 0.000 |
| shape_integrated | 3 | 0.912 | 0.906 | 0.898 | optimal | 0.000 |
| shape_integrated | 4 | 0.953 | 0.942 | 0.941 | optimal | 0.000 |
| shape_integrated | 5 | 0.970 | 0.960 | 0.978 | optimal | 0.000 |
| shape_integrated | 6 | 0.980 | 0.972 | 0.966 | optimal | 0.000 |
| modular | 1 | 0.809 | 0.809 | 0.821 | optimal | 0.000 |
| modular | 2 | 0.952 | 0.914 | 0.962 | optimal | 0.000 |
| modular | 3 | 0.977 | 0.972 | 0.983 | optimal | 0.000 |
| modular | 4 | 0.990 | 0.982 | 0.983 | optimal | 0.000 |
| modular | 5 | 0.995 | 0.991 | 0.988 | optimal | 0.000 |
| modular | 6 | 0.997 | 0.994 | 0.988 | optimal | 0.000 |

`val_cov`: the training-selected set scored on held-out participants (participant-level split).
`val_p05/p95`: bootstrap interval that re-runs selection on resampled training heads.

## Cheapest tooling reaching each coverage target (training heads)

Tooling costs are placeholder AUD assumptions (config `costs`), for ranking only.

| architecture | target | status | mip_gap | tooling_cost_AUD | crown_families | press_die_sets | press_dies | complete_assemblies | train_cov | val_cov |
|---|---|---|---|---|---|---|---|---|---|---|
| size_only | 0.850 | infeasible_target | nan | nan | 0 | 0 | 0 | 0 | 0.000 | 0.000 |
| size_only | 0.900 | infeasible_target | nan | nan | 0 | 0 | 0 | 0 | 0.000 | 0.000 |
| size_only | 0.950 | infeasible_target | nan | nan | 0 | 0 | 0 | 0 | 0.000 | 0.000 |
| shape_integrated | 0.850 | optimal | 0.000 | 96000.000 | 2 | 2 | 4 | 2 | 0.855 | 0.872 |
| shape_integrated | 0.900 | optimal | 0.000 | 144000.000 | 3 | 3 | 6 | 3 | 0.910 | 0.912 |
| shape_integrated | 0.950 | optimal | 0.000 | 192000.000 | 4 | 4 | 8 | 4 | 0.952 | 0.931 |
| modular | 0.850 | optimal | 0.000 | 75000.000 | 2 | 2 | 4 | 2 | 0.862 | 0.849 |
| modular | 0.900 | optimal | 0.000 | 78000.000 | 2 | 2 | 4 | 4 | 0.901 | 0.912 |
| modular | 0.950 | optimal | 0.000 | 81000.000 | 2 | 2 | 4 | 6 | 0.952 | 0.962 |

## Recommended exploratory set

cheapest modular set reaching 0.9 on training heads: `S13-L11, S13-L14, S13-L20, G055-L11`

| crown_id | inner_length | inner_breadth | inner_height_above_tragion | crown_mass_kg_est | status |
|---|---|---|---|---|---|
| S13 | 264.960 | 220.121 | 164.581 | 2.890 | EXPLORATORY |
| G055 | 270.000 | 219.000 | 175.500 | 2.980 | EXPLORATORY |

Exclusion reasons (heads not fitted by the recommended set; a head may have several):

| status | n |
|---|---|
| reason:pad_too_loose | 38 |
| reason:pad_too_tight | 20 |
| reason:field_of_view | 5 |
| reason:pad_between_steps | 2 |
| reason:nose | 2 |

Per-head assignment, pose and pad recipe: `assignments.csv`. Excluded-head characteristics:
`excluded_characteristics.csv`. CAD (EXPLORATORY): `cad/`.

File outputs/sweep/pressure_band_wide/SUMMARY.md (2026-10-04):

# Run summary: pressure_band_wide

**ansur2 surrogate (scalar measurements + assumed shape priors)**. All coverage figures are *geometric feasibility* under the configured
assumptions. `validated_fit` is **unevaluated** for every head because foam stability, retention,
protective-stack and motion-range criteria have no measured data yet (spec section 7).

- Heads: 600; catalogue: 97 crowns, 2619 crown+lower assemblies
- Calibrated radial offset 30.0 mm; allowances 7.32 mm
  (incl. sampling bound 1.82 mm); fillable pad gap 11.9-27.5 mm
- Config hash `a3dc7ca45f05`, seed 20261003, runtime 669 s
- Optimality is over this finite catalogue only; it is not a global optimum over surfaces.

## Coverage by number of press-die families

| architecture | families | train_cov | train_cov_greedy | val_cov | status | mip_gap |
|---|---|---|---|---|---|---|
| size_only | 1 | 0.672 | 0.672 | 0.720 | optimal | 0.000 |
| size_only | 2 | 0.802 | 0.767 | 0.801 | optimal | 0.000 |
| size_only | 3 | 0.844 | 0.843 | 0.863 | optimal | 0.000 |
| size_only | 4 | 0.866 | 0.857 | 0.882 | optimal | 0.000 |
| size_only | 5 | 0.879 | 0.869 | 0.887 | optimal | 0.000 |
| size_only | 6 | 0.889 | 0.878 | 0.887 | optimal | 0.000 |
| shape_integrated | 1 | 0.813 | 0.813 | 0.816 | optimal | 0.000 |
| shape_integrated | 2 | 0.922 | 0.889 | 0.941 | optimal | 0.000 |
| shape_integrated | 3 | 0.966 | 0.962 | 0.966 | optimal | 0.000 |
| shape_integrated | 4 | 0.987 | 0.980 | 0.978 | optimal | 0.000 |
| shape_integrated | 5 | 0.993 | 0.989 | 0.983 | optimal | 0.000 |
| shape_integrated | 6 | 0.997 | 0.993 | 0.993 | optimal | 0.000 |
| modular | 1 | 0.893 | 0.893 | 0.924 | optimal | 0.000 |
| modular | 2 | 0.987 | 0.954 | 0.985 | optimal | 0.000 |
| modular | 3 | 0.994 | 0.994 | 0.997 | optimal | 0.000 |
| modular | 4 | 0.997 | 0.997 | 0.997 | optimal | 0.000 |
| modular | 5 | 0.997 | 0.997 | 0.997 | optimal | 0.000 |
| modular | 6 | 0.997 | 0.997 | 0.997 | optimal | 0.000 |

`val_cov`: the training-selected set scored on held-out participants (participant-level split).
`val_p05/p95`: bootstrap interval that re-runs selection on resampled training heads.

## Cheapest tooling reaching each coverage target (training heads)

Tooling costs are placeholder AUD assumptions (config `costs`), for ranking only.

| architecture | target | status | mip_gap | tooling_cost_AUD | crown_families | press_die_sets | press_dies | complete_assemblies | train_cov | val_cov |
|---|---|---|---|---|---|---|---|---|---|---|
| size_only | 0.850 | optimal | 0.000 | 192000.000 | 4 | 4 | 8 | 4 | 0.852 | 0.877 |
| size_only | 0.900 | optimal | 0.000 | 480000.000 | 10 | 10 | 20 | 10 | 0.901 | 0.908 |
| size_only | 0.950 | infeasible_target | nan | nan | 0 | 0 | 0 | 0 | 0.000 | 0.000 |
| shape_integrated | 0.850 | optimal | 0.000 | 96000.000 | 2 | 2 | 4 | 2 | 0.898 | 0.929 |
| shape_integrated | 0.900 | optimal | 0.000 | 96000.000 | 2 | 2 | 4 | 2 | 0.922 | 0.941 |
| shape_integrated | 0.950 | optimal | 0.000 | 144000.000 | 3 | 3 | 6 | 3 | 0.954 | 0.962 |
| modular | 0.850 | optimal | 0.000 | 40500.000 | 1 | 1 | 2 | 3 | 0.893 | 0.924 |
| modular | 0.900 | time_limit | 0.240 | 75000.000 | 2 | 2 | 4 | 2 | 0.900 | 0.901 |
| modular | 0.950 | optimal | 0.000 | 76500.000 | 2 | 2 | 4 | 3 | 0.952 | 0.955 |

## Recommended exploratory set

cheapest modular set reaching 0.9 on training heads: `S11-L20, S19-L20`

| crown_id | inner_length | inner_breadth | inner_height_above_tragion | crown_mass_kg_est | status |
|---|---|---|---|---|---|
| S11 | 257.314 | 213.260 | 160.195 | 2.750 | EXPLORATORY |
| S19 | 275.826 | 228.603 | 171.720 | 3.090 | EXPLORATORY |

Exclusion reasons (heads not fitted by the recommended set; a head may have several):

| status | n |
|---|---|
| reason:nose | 21 |
| reason:field_of_view | 17 |
| reason:pad_too_tight | 10 |
| reason:pad_too_loose | 5 |
| reason:pad_between_steps | 2 |

Per-head assignment, pose and pad recipe: `assignments.csv`. Excluded-head characteristics:
`excluded_characteristics.csv`. CAD (EXPLORATORY): `cad/`.

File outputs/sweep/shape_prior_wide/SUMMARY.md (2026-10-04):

# Run summary: shape_prior_wide

**ansur2 surrogate (scalar measurements + assumed shape priors)**. All coverage figures are *geometric feasibility* under the configured
assumptions. `validated_fit` is **unevaluated** for every head because foam stability, retention,
protective-stack and motion-range criteria have no measured data yet (spec section 7).

- Heads: 600; catalogue: 97 crowns, 2619 crown+lower assemblies
- Calibrated radial offset 31.5 mm; allowances 8.18 mm
  (incl. sampling bound 2.68 mm); fillable pad gap 11.9-27.5 mm
- Config hash `4e25be73f9af`, seed 20261003, runtime 904 s
- Optimality is over this finite catalogue only; it is not a global optimum over surfaces.

## Coverage by number of press-die families

| architecture | families | train_cov | train_cov_greedy | val_cov | status | mip_gap |
|---|---|---|---|---|---|---|
| size_only | 1 | 0.287 | 0.287 | 0.317 | optimal | 0.000 |
| size_only | 2 | 0.415 | 0.400 | 0.480 | optimal | 0.000 |
| size_only | 3 | 0.474 | 0.474 | 0.511 | optimal | 0.000 |
| size_only | 4 | 0.509 | 0.509 | 0.553 | optimal | 0.000 |
| size_only | 5 | 0.541 | 0.541 | 0.565 | optimal | 0.000 |
| size_only | 6 | 0.565 | 0.565 | 0.579 | optimal | 0.000 |
| shape_integrated | 1 | 0.536 | 0.536 | 0.477 | optimal | 0.000 |
| shape_integrated | 2 | 0.696 | 0.692 | 0.674 | optimal | 0.000 |
| shape_integrated | 3 | 0.787 | 0.765 | 0.786 | optimal | 0.000 |
| shape_integrated | 4 | 0.845 | 0.812 | 0.854 | optimal | 0.000 |
| shape_integrated | 5 | 0.873 | 0.845 | 0.871 | optimal | 0.000 |
| shape_integrated | 6 | 0.888 | 0.877 | 0.900 | optimal | 0.000 |
| modular | 1 | 0.663 | 0.648 | 0.750 | optimal | 0.000 |
| modular | 2 | 0.830 | 0.789 | 0.813 | optimal | 0.000 |
| modular | 3 | 0.885 | 0.868 | 0.862 | optimal | 0.000 |
| modular | 4 | 0.911 | 0.899 | 0.919 | optimal | 0.000 |
| modular | 5 | 0.929 | 0.920 | 0.943 | optimal | 0.000 |
| modular | 6 | 0.940 | 0.933 | 0.924 | optimal | 0.000 |

`val_cov`: the training-selected set scored on held-out participants (participant-level split).
`val_p05/p95`: bootstrap interval that re-runs selection on resampled training heads.

## Cheapest tooling reaching each coverage target (training heads)

Tooling costs are placeholder AUD assumptions (config `costs`), for ranking only.

| architecture | target | status | mip_gap | tooling_cost_AUD | crown_families | press_die_sets | press_dies | complete_assemblies | train_cov | val_cov |
|---|---|---|---|---|---|---|---|---|---|---|
| size_only | 0.850 | infeasible_target | nan | nan | 0 | 0 | 0 | 0 | 0.000 | 0.000 |
| size_only | 0.900 | infeasible_target | nan | nan | 0 | 0 | 0 | 0 | 0.000 | 0.000 |
| size_only | 0.950 | infeasible_target | nan | nan | 0 | 0 | 0 | 0 | 0.000 | 0.000 |
| shape_integrated | 0.850 | optimal | 0.000 | 240000.000 | 5 | 5 | 10 | 5 | 0.859 | 0.840 |
| shape_integrated | 0.900 | optimal | 0.000 | 336000.000 | 6 | 7 | 14 | 7 | 0.903 | 0.909 |
| shape_integrated | 0.950 | optimal | 0.000 | 624000.000 | 12 | 13 | 26 | 13 | 0.951 | 0.926 |
| modular | 0.850 | optimal | 0.000 | 117000.000 | 3 | 3 | 6 | 6 | 0.854 | 0.841 |
| modular | 0.900 | optimal | 0.000 | 157500.000 | 4 | 4 | 8 | 9 | 0.903 | 0.899 |
| modular | 0.950 | optimal | 0.000 | 310500.000 | 8 | 8 | 16 | 15 | 0.950 | 0.952 |

## Recommended exploratory set

cheapest modular set reaching 0.9 on training heads: `S09-L02, S09-L20, G055-L01, G055-L11, G055-L20, G070-L13, G070-L20, G075-L20, G075-L22`

| crown_id | inner_length | inner_breadth | inner_height_above_tragion | crown_mass_kg_est | status |
|---|---|---|---|---|---|
| S09 | 255.680 | 212.411 | 158.817 | 2.720 | EXPLORATORY |
| G055 | 270.000 | 219.000 | 175.500 | 2.980 | EXPLORATORY |
| G070 | 282.000 | 219.000 | 163.500 | 3.000 | EXPLORATORY |
| G075 | 282.000 | 231.000 | 175.500 | 3.170 | EXPLORATORY |

Exclusion reasons (heads not fitted by the recommended set; a head may have several):

| status | n |
|---|---|
| reason:pad_too_tight | 21 |
| reason:pad_between_steps | 16 |
| reason:pad_too_loose | 11 |
| reason:field_of_view | 10 |
| reason:nose | 7 |

Per-head assignment, pose and pad recipe: `assignments.csv`. Excluded-head characteristics:
`excluded_characteristics.csv`. CAD (EXPLORATORY): `cad/`.

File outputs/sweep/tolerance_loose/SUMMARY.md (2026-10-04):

# Run summary: tolerance_loose

**ansur2 surrogate (scalar measurements + assumed shape priors)**. All coverage figures are *geometric feasibility* under the configured
assumptions. `validated_fit` is **unevaluated** for every head because foam stability, retention,
protective-stack and motion-range criteria have no measured data yet (spec section 7).

- Heads: 600; catalogue: 97 crowns, 2619 crown+lower assemblies
- Calibrated radial offset 33.0 mm; allowances 10.82 mm
  (incl. sampling bound 1.82 mm); fillable pad gap 11.9-27.5 mm
- Config hash `b258fe7c998a`, seed 20261003, runtime 724 s
- Optimality is over this finite catalogue only; it is not a global optimum over surfaces.

## Coverage by number of press-die families

| architecture | families | train_cov | train_cov_greedy | val_cov | status | mip_gap |
|---|---|---|---|---|---|---|
| size_only | 1 | 0.318 | 0.318 | 0.372 | optimal | 0.000 |
| size_only | 2 | 0.436 | 0.427 | 0.452 | optimal | 0.000 |
| size_only | 3 | 0.509 | 0.502 | 0.493 | optimal | 0.000 |
| size_only | 4 | 0.557 | 0.557 | 0.530 | optimal | 0.000 |
| size_only | 5 | 0.599 | 0.587 | 0.592 | optimal | 0.000 |
| size_only | 6 | 0.620 | 0.611 | 0.589 | optimal | 0.000 |
| shape_integrated | 1 | 0.673 | 0.673 | 0.603 | optimal | 0.000 |
| shape_integrated | 2 | 0.810 | 0.803 | 0.857 | optimal | 0.000 |
| shape_integrated | 3 | 0.895 | 0.880 | 0.860 | optimal | 0.000 |
| shape_integrated | 4 | 0.926 | 0.915 | 0.936 | optimal | 0.000 |
| shape_integrated | 5 | 0.952 | 0.936 | 0.932 | optimal | 0.000 |
| shape_integrated | 6 | 0.969 | 0.955 | 0.946 | optimal | 0.000 |
| modular | 1 | 0.795 | 0.795 | 0.796 | optimal | 0.000 |
| modular | 2 | 0.917 | 0.878 | 0.938 | optimal | 0.000 |
| modular | 3 | 0.961 | 0.958 | 0.952 | optimal | 0.000 |
| modular | 4 | 0.982 | 0.976 | 0.971 | optimal | 0.000 |
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

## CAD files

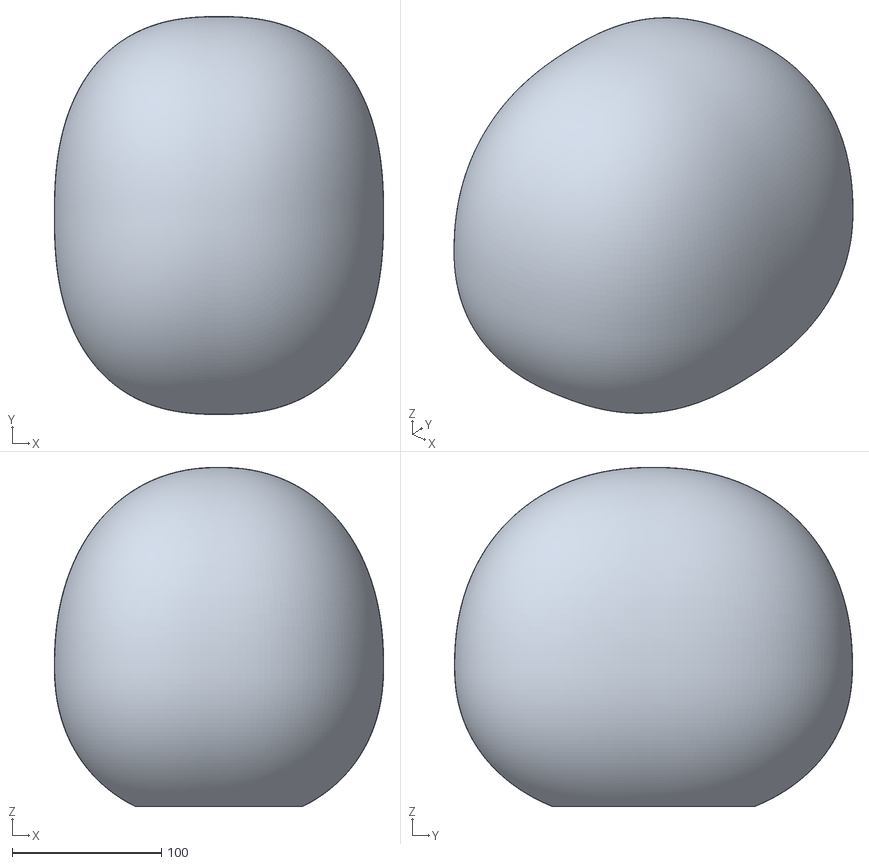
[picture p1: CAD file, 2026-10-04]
outputs/ansur2_default/cad/S13_outer.stl
220.9 x 266.9 x 227.5

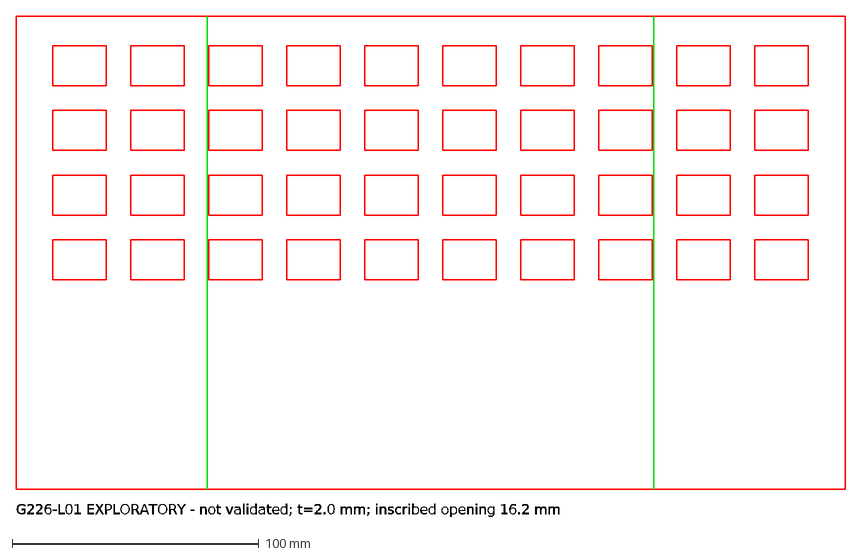
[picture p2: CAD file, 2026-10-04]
outputs/ansur2_default/cad/G226-L01_grille_blank.dxf
G226-L01 EXPLORATORY - not validated; t=2.0 mm; inscribed opening 16.2 mm

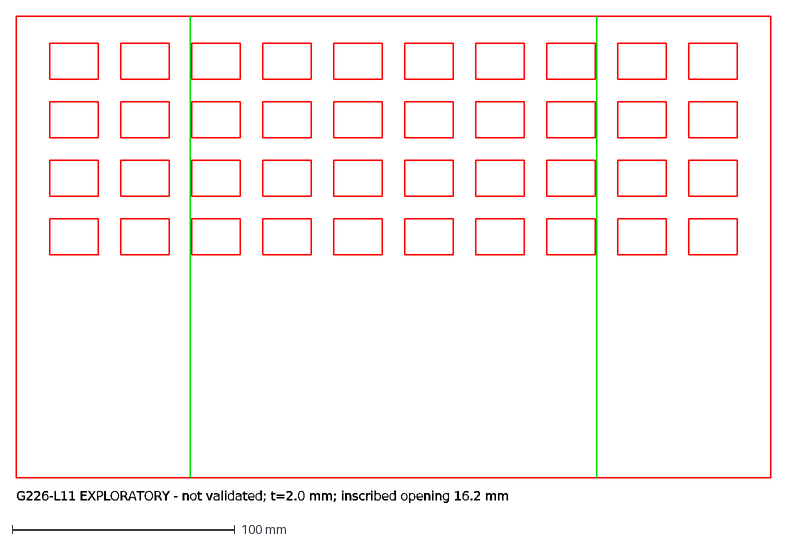
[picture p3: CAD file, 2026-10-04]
outputs/ansur2_default/cad/G226-L11_grille_blank.dxf
G226-L11 EXPLORATORY - not validated; t=2.0 mm; inscribed opening 16.2 mm

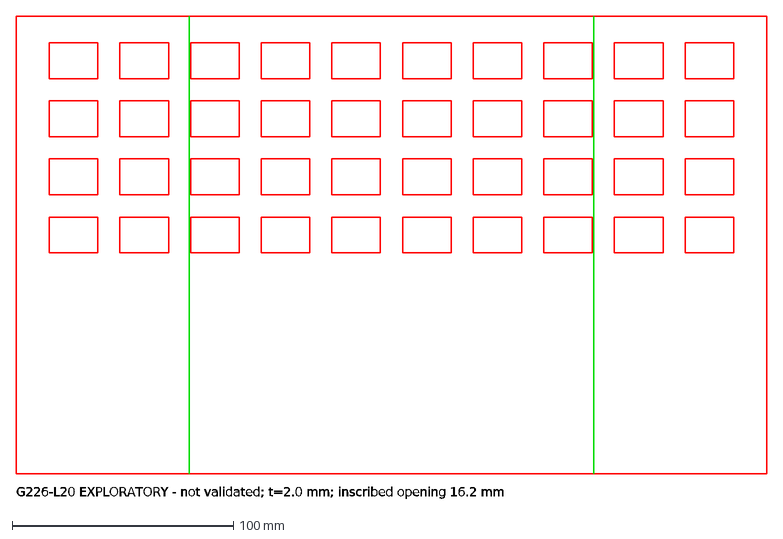
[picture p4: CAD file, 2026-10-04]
outputs/ansur2_default/cad/G226-L20_grille_blank.dxf
G226-L20 EXPLORATORY - not validated; t=2.0 mm; inscribed opening 16.2 mm

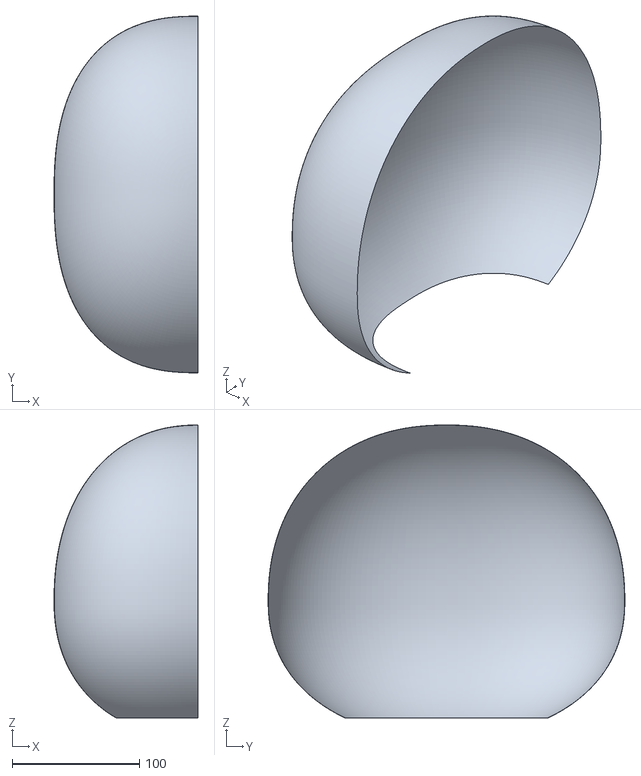
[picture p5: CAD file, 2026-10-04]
outputs/ansur2_default/cad/G226_inner_right.stl
113.0 x 280.0 x 230.0

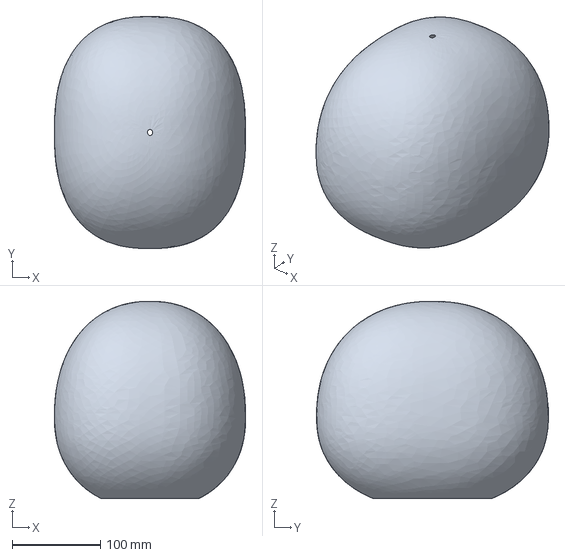
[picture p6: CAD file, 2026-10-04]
outputs/ansur2_default/cad/S13_inner.step
216.9 x 262.9 x 223.7 mm

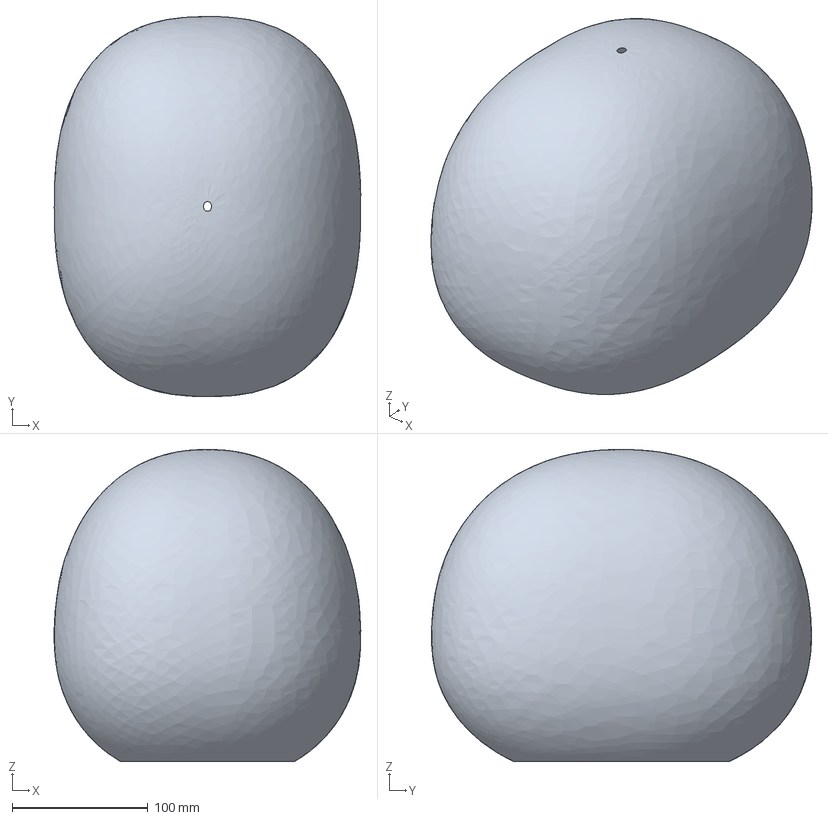
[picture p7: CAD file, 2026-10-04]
outputs/ansur2_default/cad/G226_inner.step
225.9 x 280.1 x 230.0 mm

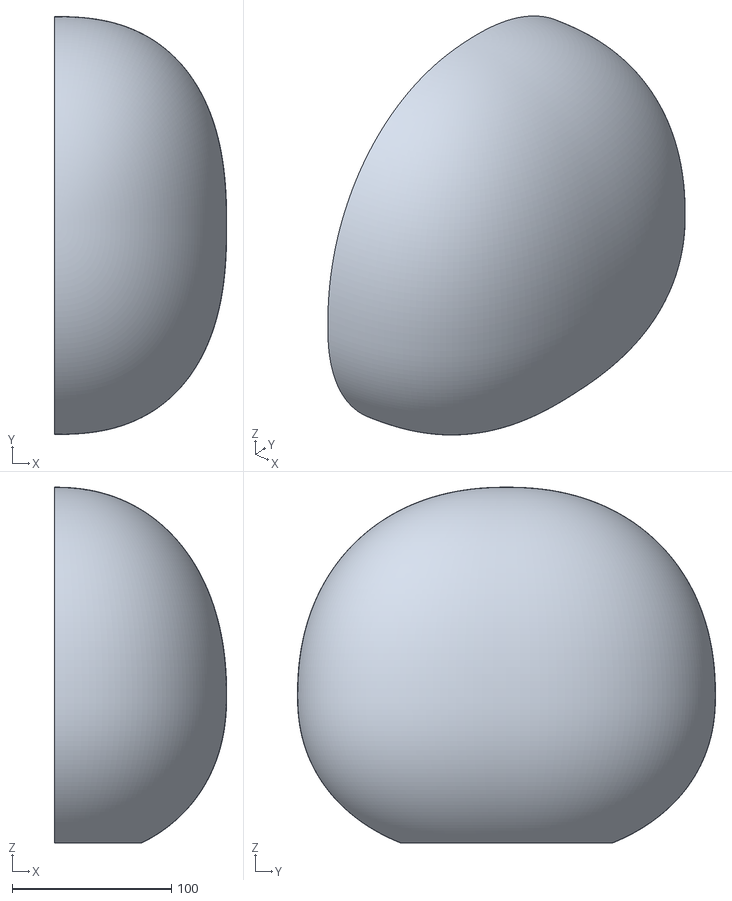
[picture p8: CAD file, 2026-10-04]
outputs/ansur2_default/cad/S13_inner_left.stl
108.4 x 262.9 x 223.7

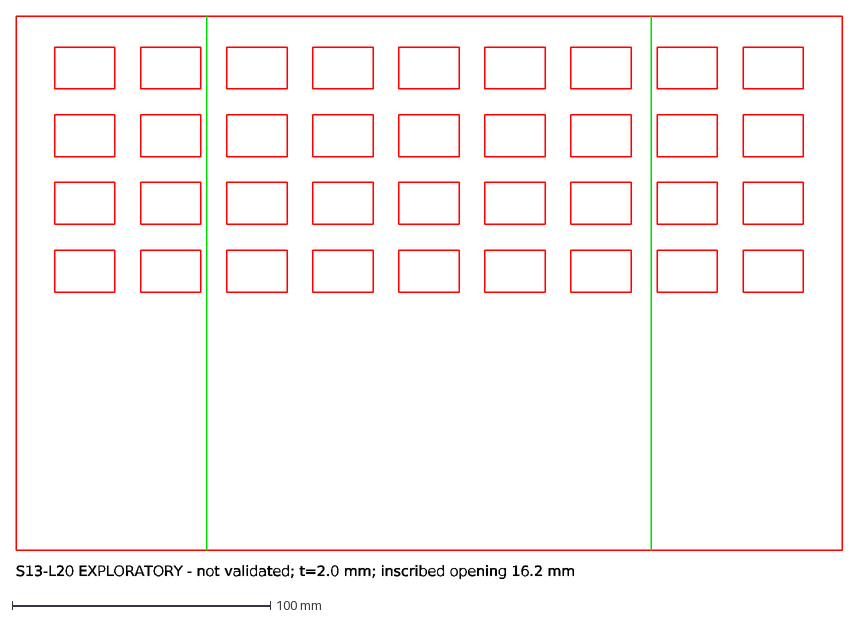
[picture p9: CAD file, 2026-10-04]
outputs/ansur2_default/cad/S13-L20_grille_blank.dxf
S13-L20 EXPLORATORY - not validated; t=2.0 mm; inscribed opening 16.2 mm

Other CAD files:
outputs/ansur2_default/cad/G226_outer.stl
outputs/ansur2_default/cad/G226_inner_left.stl
outputs/ansur2_default/cad/S13_inner_right.stl
outputs/ansur2_default/cad/G226_inner.stl
outputs/ansur2_default/cad/S13_inner.stl

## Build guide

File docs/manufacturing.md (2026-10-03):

# Forming and fabrication: comparison and assumptions

Status: **desk study.** Every number below is either cited, derived from a formula shown here, or marked [ASSUMPTION]. None of it has been validated by forming simulation or prototypes.

## 1. Rules that constrain the process

From `rules_matrix.md` (current Society V2026.0 and Lochac v3.4):

| Constraint | Consequence |
| --- | --- |
| Finished steel ≥ 1.6 mm everywhere, face guard included | Measure the thinnest point after forming and grinding, not the stock |
| A pressed or domed skull must start from ≥ 2.0 mm stock (Society "must"; Lochac "should") | 2.0 mm stock leaves at most **20% thinning** anywhere. This is the key forming limit. |
| Cold-rolled steel (Society 12.4.2.2, A1008 cited) | Use a drawing-quality cold-rolled grade (e.g. AS/NZS 1595 CA2S-E/CA3S-E, or DC04 equivalents). Confirm the supplier's elongation and r-value. |
| Rivet spacing and type (Society: no blind or pop rivets; spacing set by rivet diameter) | Applies to crown-to-lower joints if riveted rather than welded |
| 1 inch (25.4 mm) dowel must not enter any opening (Society); face guard ≥ 25.4 mm below the chin | Sets the grille opening size and the lower edge (`lower.chin_coverage_margin`) |

## 2. Architectures compared

| | A. Left/right halves, sagittal seam (working interpretation) | B. Front/back halves, coronal seam | C. Pressed crown dome + fabricated lower |
| --- | --- | --- | --- |
| Draw direction | Lateral (x) | Anterior/posterior (y) | Vertical (z) |
| Draw depth (median shell, from the catalogue) | ≈ half inner breadth, ~100–110 mm | ≈ front or rear semi-axis, ~120–130 mm | ≈ tragion-to-top height, ~150–160 mm (to the brow line) |
| Undercut-free for the convex crown? | Yes: each half projects one-to-one onto the sagittal plane | Yes | Yes, above the equator |
| Dies per family | **2** (mirror images) unless one die can be shown to form both halves, e.g. symmetric tooling with a flipped blank. The default `halves_share_die: false` counts 2. | 2 (front and rear differ) | 1 |
| Seam | Along the crest. A raised comb could hide or stiffen it, and the inner weld bead must be ground (config `seam_bead_height`). | Across the crown, in the strike zone | Crown-to-lower joint near the brow and occiput |
| Lower and face integration | Possible: each half can carry its face and cheek. Depth then grows and the draw becomes asymmetric. | Front half carries the face | Separate laser-cut and bent lower; many variants per crown |
| Effect on coverage (this toolchain) | `shape_integrated` if the lower is pressed in; `modular` if the halves are trimmed to a crown interface | Not modelled separately; same crown geometry | `modular` |

The two-half welded construction is the user's proposal, so it stays a candidate throughout. The toolchain evaluates the crown geometry independently of the split plane: the split changes die count and cost, not fit. The split plane is configurable through the cost model (`costs.halves_share_die`) and through `export.shell_meshes`, which slices on x = 0.

## 3. Press force: a first-order estimate

For a drawn shell with punch perimeter *L*, sheet thickness *t* and ultimate tensile strength *UTS*, a common first estimate of draw force is *F ≈ L · t · UTS · k*. Here *k* is between 0.6 and 1.0, depending on draw ratio. Blank-holder force adds roughly a further 30–40%. (These are textbook rules of thumb for drawing; Schuler, *Metal Forming Handbook*, ch. 4, gives this form. Treat the figures as order-of-magnitude.)

| Input | Value | Status |
| --- | --- | --- |
| Punch perimeter, architecture A (sagittal outline of a median crown, length ~250 × height ~190) | ≈ 750 mm | Derived from the catalogue geometry |
| t | 2.0 mm | Rule-driven stock |
| UTS, drawing-grade cold-rolled mild steel | 300–350 MPa | Typical datasheet range [ASSUMPTION until the grade is chosen] |
| k | 1.0 | Conservative |

The estimate is *F* ≈ 750 × 2.0 × 350 × 1.0 ≈ **525 kN**, plus about 35% for the blank holder, giving about **710 kN (~72 tonne-force)** per half. A press rated around **100–150 t** would leave margin. **This is not a press selection.** Spec section 10 requires a documented forming model: confirm with a forming simulation (e.g. AutoForm or PAM-STAMP via a toolmaker) or a prototype draw before buying or hiring a press.

## 4. Main forming risks

| Risk | Why it matters | How to settle it |
| --- | --- | --- |
| Thinning > 20% at the pole of each half (the side of the skull for A, the crown for C) | It would break the 1.6 mm finished rule | Circle-grid strain analysis on the first draws. Consider two-stage draws, draw beads and lubrication. Hot forming is a fallback. |
| Wrinkling in the flange or at the sagittal edge | Scrap and poor seam fit-up | Blank-holder pressure trials |
| Springback | Inner surface off-target, which eats into the fit tolerance (`shell.manufacturing_tolerance`, default 1.5 mm) | Scan formed parts, then compensate the die. **An offset headform is not a usable die surface** (spec section 5). |
| Weld distortion along a 400–500 mm seam | Asymmetric halves | Fixture with tack sequence and backstep welding; scan before and after welding |
| Grinding the seam flush | Local thinning below 1.6 mm | Measure ultrasonically at the seam; limit grind depth |

## 5. Cost model (placeholders)

The figures are in `config/default.yaml` under `costs`. They are **[ASSUMPTION] placeholders** used only to rank options, and must be replaced with toolmaker quotes.

| Item | Placeholder (AUD) |
| --- | --- |
| Die per pressed half | 18,000 |
| Extra die cost to integrate face and jaw into the pressing (per half) | 6,000 |
| Lower variant design (laser program, bend fixture, first-article check) | 1,500 |
| Crown unit cost (blank, press time, trim, weld, grind) | 260 |
| Lower unit cost (laser, bend, attach) | 120 |

**Unit cost at batch volume V per family:** (die set + Σ lower designs) / V + crown unit + lower unit + liner + inspection + rejects. Rejects and inspection are unquantified. The min-cost tables in each run's `SUMMARY.md` show the tooling term only.

## 6. Inspection (to define before production; Gate D)

- **Thickness:** ultrasonic gauge at the predicted most-strained points, trim edges and ground seams. Accept only at ≥ 1.6 mm at every point.
- **Geometry:** a structured-light scan of the inner surface compared with the CAD inner surface. Report the deviation map and accept within the tolerance assumed in the fit analysis.
- **Seams:** visual inspection plus a cut-and-etch macro on first articles. Specify the bead height after grinding.
- **Grille:** check every opening with a 25.4 mm dowel; measure ligament widths.

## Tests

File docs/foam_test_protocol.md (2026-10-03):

# Liner foam and stack test protocol (Gate B)

Status: **protocol only, no measurements yet.** Every foam property in `config/default.yaml` is a placeholder with `measured: false`. While that holds, the fit evaluator reports stability and protective-stack criteria as *unevaluated*.

## 1. Materials

The test set is two candidate grades, configured as `soft` and `firm`. Record each in the property schema (section 4) by **material ID**: supplier, product code, lot, nominal density and cell type. Density alone does not describe a foam.

Test every combination of the cover fabric and attachment method (adhesive, hook-and-loop, snap) that the liner design might use.

## 2. Coupon tests (per grade, n ≥ 3 coupons per condition)

| Property | Method (indicative) | Conditions |
| --- | --- | --- |
| Quasi-static compression stress–strain to 80% | 50×50 mm coupon, at the catalogue thicknesses, using a universal tester or a calibrated weight-and-dial rig | 10 mm/min, then 100 mm/min, to show rate dependence |
| Hysteresis (loading and unloading loop) | Same rig, 5 cycles | Report cycle 1 and cycle 5 |
| Compression set | 25% (and 50%) strain held for 22 h, measured 30 min and 24 h after release. Use ISO 1856 / ASTM D3574 style. | 23 °C and 40 °C |
| Creep under fit preload | Constant 5 kPa and 10 kPa for 4 h | 23 °C |
| Shear stiffness G | Double-lap shear coupon | Small strain (< 20%) |
| Temperature sensitivity | Repeat the stress–strain test | 10 °C, 23 °C, 40 °C. Australian summer events matter. |
| Moisture and sweat | Soak in saline, drain, repeat the stress–strain test | Wet and dry |
| Ageing | Repeat compression set after 50 h at 70 °C | — |

Impact-rate behaviour belongs to Gate E. It needs a drop rig and qualified input, and is **not** covered here.

## 3. Stack-on-headform stability tests

1. **Headform.** A rigid headform close to the population median, such as a printed NIOSH/ISO medium form or an EN 960 J/M form if obtained, covered with a thin cap that matches the hair allowance.
2. **Shell.** A printed or formed shell from a candidate crown. Fit the pad recipe the evaluator predicts for that headform.
3. **Preload.** Install with the predicted compression and record the actual installed thickness at each pad.
4. **Lateral loads.** Apply forces of 20, 40 and 60 N (forward, rearward, left and right) through a fixture at brow height. Record shell translation relative to the headform in mm, using dial gauges or optical markers.
5. **Rotation.** Apply torques of 1, 2 and 3 N·m in pitch, yaw and roll. Record rotation in degrees.
6. **Creep and recovery.** Hold the largest load for 5 min and record recovery 1 min after release.
7. **Variants.** Repeat for each candidate stack (base plus fitting layers) and each attachment method.

**Allowable movement** is an engineering decision still to be made. Record the rationale with it. Start from these limits:

- the eye line stays inside the grille's clear band (config `lower.eye_band`);
- the face never closes to less than `lower.nose_clearance_min` from the grille;
- the occipital edge never uncovers.

Keep the normal-use limits separate from retention and roll-off tests, and from impact testing.

## 4. Property schema (import path)

Measured data goes in `data/raw/foam/<material_id>/` as CSV, one file per test. The columns are `test, coupon, condition, strain, stress_kPa, time_s, temperature_C, notes`.

A `config/materials/<material_id>.yaml` file then summarises:

```yaml
material_id: SUPPLIER-PRODUCT-LOT
measured: true
E_kPa_secant_10pct: ...      # replaces the linear placeholder in the screening model
stress_strain_curve: data/raw/foam/<id>/compression_10mm_min.csv
G_kPa: ...
densification_strain: ...
compression_set_pct_22h: ...
creep_strain_4h_at_5kPa: ...
temperature_factor_10C: ...
sources: [file list with sha256]
```

The current screening model (`src/scahelm/liner.py`) assumes linear, ideally bonded layers in series. Once curves exist, replace `choose()` with an interpolation of the measured stack curve. Keep the same check names so reports stay comparable.

## 5. What the bench data should settle first

These are ordered by how much they move the coverage results; see `outputs/sweep/sweep_summary.csv`:

1. The usable compression band for fitting, which sets the fillable gap window.
2. Maximum total liner depth before stability fails.
3. Whether firm fitting layers on a soft base resist shear better than a single thick soft pad. The spec's "soft impact layer, firm fitting layer" idea is **unproven**.

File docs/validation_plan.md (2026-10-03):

# Physical validation plan and decision gates

Each gate lists what it establishes, the work, and the exit criterion. Software verification is covered by `tests/`; this file covers the physical evidence.

## Gate A: data

- **Establishes:** enough cranial information and a defensible population.
- **Current state:** **not passed.** Only scalar proxies exist (ANSUR II). The model is a labelled surrogate.
- **Work:** follow the acquisition plan in `data_sources.md`: RMIT authors, then Headspace/LYHM via an academic partner, then a Lochac scan day. Ingest the NIOSH 2003 table as a civilian cross-check.
- **Exit:** at least 100 consenting Lochac fighters scanned with full cranium and their usual arming cap, plus a tape-measure check. Coverage predictions from the ANSUR surrogate are compared with predictions from those scans.

## Gate B: liner

- **Establishes:** measured foam behaviour and justified normal-use movement limits.
- **Work:** `foam_test_protocol.md`.
- **Exit:** both foam grades imported with `measured: true`; movement limits written down with their rationale; coverage recomputed. Stability criteria then move from *unevaluated* to pass/fail.

## Gate C: geometry (non-combat fit prototypes)

- **Work:**
  - 3-D print or vacuum-form the inner surfaces of the recommended crowns (STL in `outputs/*/cad`).
  - Recruit wearers from three groups in `assignments.csv`: near the edges of each family's coverage, just outside the selected set, and deliberately excluded (one per main exclusion reason).
  - Fit the predicted pad recipe.
  - Record the eye line relative to the grille, pad compression, hot spots, and movement under the Gate B loads.
- **Exit:** predicted and observed fit/no-fit agree on at least 90% of boundary cases, and pad recipes match within one catalogue step. Disagreements are traced to a model input.

## Gate D: manufacture

- **Work:** form and weld steel prototypes of one family, then run the inspection list in `manufacturing.md` section 6. Scan the formed geometry and re-run the fit evaluator on the as-formed inner surface.
- **Exit:** ≥ 1.6 mm everywhere, deviation within the assumed tolerance, sound seams, and every grille opening refusing the 25.4 mm dowel.

## Gate E: protection and use

- **Work:** with qualified input (e.g. a university impact lab), develop instrumented impact, deformation, retention and repeat-impact tests on **complete assemblies**, including liners and attachments. Base the protocol on a recognised helmet standard's apparatus, adapted to rattan-strike energies, which still need establishing. **Never use wearers as impact-test subjects.**
- **Exit:** a documented test report. Passing marshal inspection is rules compliance, not evidence of impact attenuation; keep the two separate.

## Order of measurements that most reduce uncertainty

This order is my engineering judgement, informed by the sweep:

1. Foam compression band and maximum liner depth (Gate B). This sets the fillable gap window that drives coverage.
2. Full-head scans of real fighters (Gate A). They replace the independent shape priors.
3. As-formed tolerance and springback (Gate D). Tolerance enters every clearance.
4. The Lochac sex mix and arming-cap thickness. They are cheap to collect at one event.

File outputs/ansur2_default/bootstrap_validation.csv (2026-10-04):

architecture | families | b | val_cov
size_only | 1 | 0 | 0.44096022233145526
size_only | 2 | 0 | 0.5883871516618143
size_only | 3 | 0 | 0.6649062275494385
size_only | 4 | 0 | 0.7114029946685825
size_only | 5 | 0 | 0.7297699171928763
size_only | 6 | 0 | 0.7618680757741898
size_only | 1 | 1 | 0.44096022233145526
size_only | 2 | 1 | 0.6264633039664235
size_only | 3 | 1 | 0.6459598442167355
size_only | 4 | 1 | 0.7257136915340114
size_only | 5 | 1 | 0.7373690777781979
size_only | 6 | 1 | 0.7773669981472378
size_only | 1 | 2 | 0.44096022233145526
size_only | 2 | 2 | 0.6264633039664235
size_only | 3 | 2 | 0.6714343781903429
size_only | 4 | 2 | 0.7174764623586797
size_only | 5 | 2 | 0.7521051537036336
size_only | 6 | 2 | 0.7683669225242937
size_only | 1 | 3 | 0.4499016901727985
size_only | 2 | 3 | 0.6264633039664235
size_only | 3 | 3 | 0.6566983022649072
size_only | 4 | 3 | 0.7075301546489204
size_only | 5 | 3 | 0.7521051537036336
size_only | 6 | 3 | 0.7697092297803152
size_only | 1 | 4 | 0.4499016901727985
size_only | 2 | 4 | 0.6264633039664235
size_only | 3 | 4 | 0.6649062275494385
size_only | 4 | 4 | 0.7052709191968844
size_only | 5 | 4 | 0.7349264566869589
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

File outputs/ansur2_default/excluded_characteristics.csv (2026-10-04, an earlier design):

sex | status | n | head_length_mean | head_breadth_mean | head_circumference_mean | tragion_top_mean | menton_sellion_mean
F | excluded | 109 | 184.5 | 147.5 | 549.8 | 122.9 | 112.0
F | geometric_feasible | 546 | 190.9 | 148.0 | 564.1 | 127.1 | 113.3
M | excluded | 99 | 200.6 | 155.8 | 577.9 | 132.9 | 122.8
M | geometric_feasible | 1246 | 199.6 | 154.3 | 574.4 | 131.3 | 122.5
all | reason:field_of_view | 71
all | reason:pad_too_loose | 68
all | reason:pad_too_tight | 32
all | reason:nose | 28
all | reason:pad_between_steps | 14
all | reason:unpadded_gap | 1

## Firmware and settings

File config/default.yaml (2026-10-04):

# Default scenario for the SCA helm fit/coverage toolchain.
#
# Every number here carries a `status` in the comments:
#   [RULE]        from the rules register (config/rules_register.yaml)
#   [DATA]        derived from a recorded data source
#   [ASSUMPTION]  engineering placeholder chosen for this exploratory run; replace with
#                 measurement before relying on any result that is sensitive to it
#   [DECISION]    a design/process decision, not a fact
#
# Units: millimetres, newtons, kPa, degrees, AUD. Frame: x lateral (+ = wearer's left),
# y anterior, z superior; origin at the mid-point between the two tragions, z = 0 is the
# horizontal plane through tragion (a proxy for the Frankfort plane).

units: {length: mm, pressure: kPa, angle: deg, currency: AUD}
seed: 20261003

population:
  target_coverage: 0.90                 # [DECISION] spec section 1
  # Denominator proxy: ANSUR II (US Army 2012) re-weighted by sex. Lochac fighter sex mix is
  # unknown; 0.15 female is an [ASSUMPTION] to be replaced by a marshal-roster count.
  female_fraction: 0.15
  max_participants: 3000                # [DECISION] subsample for run time; stratified by sex
  validation_fraction: 0.30             # [DECISION] participant-level held-out split

head_model:
  # Shape parameters ANSUR II does not measure. All [ASSUMPTION] priors (mean, sd) to be
  # replaced from 3-D scans. Each is sampled independently: correlation is unknown, which is
  # the main reason this is labelled a surrogate.
  f_front: [0.50, 0.020]     # fraction of head length anterior to tragion
  z_equator: [32.0, 5.0]     # height of max length/breadth plane above tragion
  n_vertical: [2.3, 0.15]    # superquadric vertical exponent (2 = ellipsoidal)
  c_low_frac: [0.55, 0.05]   # depth of occiput below equator as a fraction of tragion-vertex height
  pupil_z: [17.0, 3.0]       # pupil height above tragion plane
  sellion_z_minus_pupil: [4.0, 2.0]
  nose_protrusion: [22.0, 3.0]   # pronasale anterior to sellion
  pupil_setback: [12.0, 3.0]     # pupil posterior to sellion
  chin_setback: [12.0, 6.0]      # menton posterior to sellion
  ear_protrusion_default: [21.0, 3.0]  # used only if the data source lacks it
  hair_allowance: 3.0        # [ASSUMPTION] hair + arming cap, subtracted from all clearances
  sample_spacing: 7.0        # head surface sample spacing (mm); bound reported per run

shell:
  material: {name: mild steel, thickness: 2.0, density_g_cm3: 7.85}   # [DECISION] spec s10; see rules for minimum
  seam_bead_height: 1.5      # [ASSUMPTION] inner weld bead after grinding, sagittal seam
  seam_bead_halfwidth: 4.0
  manufacturing_tolerance: 1.5   # [ASSUMPTION] inner-surface deviation after forming/welding
  measurement_uncertainty: 1.0   # [ASSUMPTION] head measurement repeatability
  min_curvature_radius: 25.0     # [ASSUMPTION] press-compatible minimum radius
  n_vertical: 2.2                # shell-family shape exponents [DECISION]
  sample_spacing: 5.0            # shell inner-surface sampling for distance queries
  plane_neighbours: 24           # tangent planes per distance query (see fit.py)
  field_spacing: 2.0             # distance-field grid (mm); exact re-check near thresholds
  field_eps: 0.1                 # minimum re-check band (mm); raised to 3x measured error
  crown_bottom_z: -35.0          # lowest z of crown region tested for fit (rear)
  brow_z: 26.0                   # face region (front, below this z) is handled by the lower component
  face_half_angle: 55.0          # azimuth half-width of face region

pose:
  dy: [-6, -3, 0, 3, 6]               # [DECISION] bounded rigid translation grid (mm)
  dz: [-12, -9, -6, -3, 0, 3, 6, 9, 12]
  pitch: [0]                          # surrogate heads carry no pitch information
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

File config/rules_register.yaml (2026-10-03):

# SCA armoured (rattan) combat helm rules register
# Scope: Kingdom of Lochac (AU/NZ) + SCA Inc. Society minimums.
# text_type: "quote" = verbatim from source; "paraphrase" = close paraphrase.
# applies_to: armoured = all armoured (rattan) combat; missile = only scenarios with
#   combat archery arrows/bolts (Lochac) ; both = applies in either.
# quantitative: list of {quantity, value, unit, comparator} or null.
# status: verified_current = wording verified on 2026-10-03 in the current source;
#   needs_confirmation = wording verified but which rule governs in Lochac, or its
#   interpretation, is unresolved (see docs/rules_matrix.md "Open questions").
# Design policy suggestion (not a rule): where Lochac v3.4 and Society 2026 differ,
#   design to the stricter of the two.

retrieved: 2026-10-03

sources:
  - id: LOCHAC-FH-WIKI
    title: "Lochac Armoured Combat Fighters' Handbook - Armoured Combat:Armour requirements (chapter 7)"
    issuer: "Kingdom of Lochac Marshallate (approved by Board of SCA Australia Ltd and Committee of SCA NZ Inc)"
    version: "v3.4 (wiki page revision oldid=8765, page last modified 15 July 2025)"
    effective_date: 2024-07-27
    url: "https://rules.marshal.lochac.sca.org/index.php/Armoured_Combat:Armour_requirements"
    authority_status: current
    notes: >-
      Main page states "These rules are currently the official rules for Lochac. They have been
      approved by the Board of SCA Ltd and Committee of SCANZ." Handbook page states v3.4 rule
      changes came into effect 27 July 2024. Change log shows only link fixes since (24 Feb 2025,
      12 July 2025); no newer Lochac armoured handbook version found. Section numbers are taken
      from the PDF rendering (LOCHAC-FH-PDF-2026).

  - id: LOCHAC-FH-PDF-2026
    title: "Kingdom of Lochac Fighters' Handbook (PDF render of the wiki)"
    issuer: "Kingdom of Lochac Marshallate"
    version: "Version 3.4 July 2024; 'PDF generated: January 31, 2026'"
    effective_date: 2024-07-27
    url: "https://rules.marshal.lochac.sca.org/index.php/Special:MakePdfBook/render/Armoured_Combat_-_Fighters_Handbook"
    authority_status: current
    notes: >-
      Live PDF generated from the wiki. Helm-related text of sections 7.4-7.7 and 7.15.2 is
      word-for-word identical to the July 2024 PDF (checked by normalised diff).

  - id: LOCHAC-FH-PDF-2024
    title: "Fighters_Handbook_v3.4_-_July_2024.pdf"
    issuer: "Kingdom of Lochac Marshallate"
    version: "Version 3.4 July 2024; 'PDF generated: July 25, 2024'"
    effective_date: 2024-07-27
    url: "https://rules.marshal.lochac.sca.org/images/b/bc/Fighters_Handbook_v3.4_-_July_2024.pdf"
    authority_status: current
    notes: >-
      Same rule content as current; static snapshot. The originally supplied URL
      https://sca.org.nz/wiki/images/b/bc/Fighters_Handbook_v3.4_-_July_2024.pdf now redirects to
      the Lochac rules wiki Main Page (HTML), not the PDF; the file is served at the URL above.
      Handbook itself warns saved copies go stale; prefer LOCHAC-FH-WIKI.

  - id: LOCHAC-NZ-LEGACY
    title: "sca.org.nz/wiki Armoured_Combat:Armour_Requirements (legacy URL)"
    issuer: "SCA New Zealand (legacy host of Lochac rules wiki)"
    version: "n/a"
    effective_date: null
    url: "https://sca.org.nz/wiki/index.php?title=Armoured_Combat:Armour_Requirements"
    authority_status: superseded
    notes: >-
      Returns 'There is currently no text in this page' (capital-R title no longer exists; wiki
      migrated to rules.marshal.lochac.sca.org in Oct 2025 per Main Page news). Use LOCHAC-FH-WIKI.

  - id: LOCHAC-GLOSSARY
    title: "Lochac Fighters' Handbook - Armoured Combat:Glossary"
    issuer: "Kingdom of Lochac Marshallate"
    version: "v3.4 (oldid=8670, last modified 12 July 2025)"
    effective_date: 2024-07-27
    url: "https://rules.marshal.lochac.sca.org/index.php/Armoured_Combat:Glossary"
    authority_status: current
    notes: "Definitions of Bars, Gauge, Resilient foam, Rigid material, Steel. Contains a bar-diameter figure inconsistent with 7.5.4 (see open questions)."

  - id: LOCHAC-CHANGELOG
    title: "Lochac Armoured Combat:Change log and Previous change logs"
    issuer: "Kingdom of Lochac Marshallate"
    version: "v3.4 + link fixes to 12 July 2025"
    effective_date: 2024-07-27
    url: "https://rules.marshal.lochac.sca.org/index.php/Armoured_Combat:Change_log"
    authority_status: current
    notes: >-
      v3.4 made no helm changes. July 2021 changes: '7.4.1.3 - updated to clarify that the metal
      for helmets needs to be at least 1.6mm thick when completed'; added 7.5.7.g (maille <=5mm)
      and 7.5.8 (screening secured against sideways and vertical movement). Previous logs at
      https://rules.marshal.lochac.sca.org/index.php/Armoured_Combat:Previous_change_logs
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

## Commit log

2026-10-03 Add exploratory toolchain for a family of pressed SCA helms
    Implements steps 1-5 of the v0.1 design spec as a reproducible Python
    pipeline: rules and data-source registers, a surrogate head model built
    from ANSUR II scalar measurements, candidate crown and lower-component
    catalogues, a fit predicate that reports pass/fail/unevaluated per
    criterion, and a MILP shell-family selector checked against exhaustive
    enumeration. All results are geometric feasibility only; liner,
    retention and protection criteria stay unevaluated until tested.
    Claude-Session: https://claude.ai/code/session_01SK1FphV7hxKLaid4vrrxEp
    [ANSUR_II_FEMALE_Public.csv, ANSUR_II_MALE_Public.csv, ansur2_canonical.csv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]
2026-10-04 Add ANSUR II surrogate run, findings draft, and solver/export fixes
    Main run over 2,000 ANSUR II participants with a held-out split and
    bootstrap intervals. The modular architecture (pressed crowns plus
    laser-cut lowers) reaches ~92% held-out geometric coverage with two
    crown families; a size-only family with a fixed lower plateaus near 78%.
    Solver: HiGHS via highspy with a greedy warm start and exact pruning of
    dominated assemblies, replacing scipy.milp, which returned solutions worse
    than greedy on the full catalogue. Adds a size-only-with-lower-variants
    architecture to separate crown shape from lower choice.
    Export: STEP now works with OCP 8 and is checked against the analytic
    surface;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
    [G226-L01_grille_blank.dxf, G226-L11_grille_blank.dxf, G226-L20_grille_blank.dxf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]
2026-10-04 Add sensitivity sweep and complete the findings
    Nine scenarios over 600 participants on a coarser catalogue. Maximum
    liner depth dominates: 25 mm needs six modular crown families for 90%
    coverage and 35 mm needs one. Widening the unmeasured shape priors moves
    the answer from two to four. Corrects the earlier claim that size-only
    crowns with a fixed lower can never reach 90%: with a wide pressure band
    or tight tolerances they can, using 10-12 sizes.
    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
    [assignments.csv, candidate_crowns.csv, candidate_lowers.csv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]
